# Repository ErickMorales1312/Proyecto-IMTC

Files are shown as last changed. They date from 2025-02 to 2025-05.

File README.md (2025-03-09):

# Proyecto-IMTC
**IoT Project for Autonomous Firefighting and Fire Detection System**

## Structure
This repo consists of the following folders:
1. **Scripts**: This folder is used for programming ESP32 (robot, cloud, detection modules).
2. **KiCad**: Electronic design projects for robot and detection modules, footprints, datasheet, BOM, etc.
3. **Docs**: Word, ppt, excel documents.
4. **Workflow**: Algorithms designed (diagrams, etc).
5. **Test**: Save simple codes for testing components.

**Commits**: 
For better organization, set commits as:
- chore: Updates of tasks
- Test: Testing components, repetitive code useful
- feat: Adding new feature on the project
   
## Step by Step Guide

### Setup
1. **Install Git Bash**
   - Download and install Git Bash from: https://gitforwindows.org/

### Configure Git
   - Set your username and email in Git Bash or command prompt.
       ```bash
        git config --global user.name "Your Name"
        git config --global user.email "your.email@example.com"

**Note** You can refer to this YouTube tutorial for guidance. (https://www.youtube.com/watch?v=8JJ101D3knE)

### Clone Repository
1. **Get the Repository Link**
   - Go to Proyecto-IMTC GitHub Repository.
   - Click on the green "Code" button and copy the HTTP link.

2. **Clone the Repository**
   - Open File Explorer and navigate to the folder where you want to save the repository.
   - Open Git Bash in the selected directory and run the following command:
     ```bash
     git clone <HTTP_LINK>

### Using Command Prompt 
You can use git -h to see more details about each Git instruction. 

## Commits and Create New Branches
### 1. Create a New Branch
   - Open the command prompt, locate the repository folder and run the following command:
     ```bash
     git branch <Name of the new branch>

### 2. **Checkout**
   - Change the main branch to new branch using the following command:
     ```bash
     git checkout <Name of the new branch>
   Then, you can save your work on this branch and commit changes.

### 3. **Commit changes**
   - Add modified files using:
     ```bash
        git add <name of the file> #for a specific file
        git add . #for all updated files
   - Make a commit 
     ```bash
        git commit -m <"name of commit">

### 4. **Push Branch to Remote**
   - At this point, your local changes are stashed temporarily, but to save your changes on the branch, you should push the branch to remote repository, using:
      ```bash
      git push origin <Name of the new branch>

### 5. **Create a PR**
   - Make a PR to merge your changes into main branch.

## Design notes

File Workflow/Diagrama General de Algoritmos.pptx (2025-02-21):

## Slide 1

IoT Autonomous Fire Detection and Firefighting System

Servicio en la nube

1. Escuchar continuamente por nueva informaciónón proveniente de los módulos de detección
2. En el momento en el que reciba nueva información, enviarla al vehículo

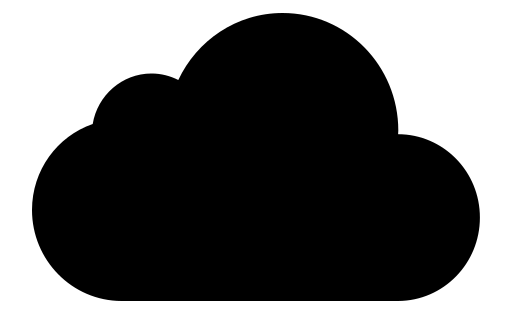
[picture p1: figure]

Vehículo autónomo de respuesta

Módulos de detección

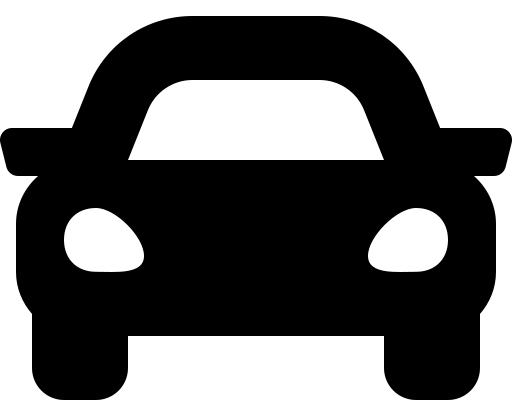
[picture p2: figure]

1. Escuchar continuamente por señales de alerta
2. En el momento en el que reciba una señal de alerta, dirigirse a la localización GPS recibida
3. Mitigar el incendio

1. Leer continuamente los datos de los sensores
2. Procesar los datos para definir si existe un incendio
3. En el momento en el que detecte un incendio, enviar la señal de la alerta a la nube, junto con las lecturas de los sensores y la información del GPS

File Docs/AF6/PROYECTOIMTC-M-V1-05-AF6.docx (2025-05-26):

UNIVERSIDAD AUTÓNOMA DE NUEVO LEÓN

FACULTAD DE INGENIERÍA

MECÁNICA Y ELÉCTRICA

PROYECTO DE IMTC

ACTIVIDAD FUNDAMENTAL 6:

DISEÑO MECÁNICO Y/O ELECTRÓNICO

EQUIPO 05

MATRÍCULA | NOMBRE | PE
1966252 | CONSTANTE MALDONADO KEVIN YAIR | IMC
1964189 | MORALES ESCOBEDO ERICK RUBEN | IMC
2078113 | SANCHEZ MELENDEZ OSWALDO | IMC

TÍTULO DEL PROYECTO:

“IoT Autonomous Fire Detection and Firefighting System”

ASESOR: DR. ERICK DE JESÚS ORDAZ RIVAS

GRUPO: 008 HORA: MARTES V1

SEMESTRE: ENERO - JUNIO 2025

FECHA DE ENTREGA: 04 DE MARZO DEL 2025

CIUDAD UNIVERSITARIA A 04 DE MARZO DEL 2025

# Introducción

El desarrollo del presente proyecto implicó el diseño integral de un sistema enfocado en la detección y mitigación de incendios, mediante la implementación de un vehículo autónomo de respuesta, módulos de detección distribuidos y un sistema de almacenamiento y suministro de agua. Para lograr una solución funcional y eficiente, se llevó a cabo un diseño mecánico y electrónico cuidadosamente planificado, permitiendo la integración estructural y operativa de todos los componentes involucrados.

Desde el enfoque mecánico, se diseñaron tres elementos clave: el vehículo autónomo, los módulos de detección y el tanque de almacenamiento. El vehículo se conforma de dos estructuras principales: una base inferior, encargada de alojar los motores, el eje de las ruedas traseras y los sensores ultrasónicos, y una base superior con perforaciones destinadas a la fijación de elementos adicionales. Además, se incorporó un separador interno que divide el espacio interno en dos zonas: una para los actuadores y otra para la electrónica de control, con el objetivo de evitar interferencias y facilitar el mantenimiento. En los módulos de detección se siguió un enfoque similar, con una base inferior que permite una instalación firme de los sensores, así como pilares para el montaje del microcontrolador. Finalmente, el tanque de agua fue diseñado con aberturas estratégicas que permiten la conexión eficiente con la bomba y la manguera, asegurando el suministro del líquido ante una posible emergencia.

En cuanto al diseño electrónico, se desarrollaron dos circuitos impresos (PCB), cada uno adaptado a las necesidades del subsistema correspondiente. El circuito del vehículo autónomo integra un microcontrolador ESP32, un módulo GPS Neo-7M, un magnetómetro HMC5887, sensores ultrasónicos para navegación, un módulo L298N para el control de los motores y baterías recargables 18650 mAh como fuente de alimentación. Por otro lado, los módulos de detección están equipados con sensores de flama, gas, temperatura y humedad, todos gestionados mediante un microcontrolador ESP32 y alimentados por una batería de 3.7V. Esta disposición garantiza una operación autónoma, continua y segura en entornos dinámicos.

La relevancia de este diseño radica en su enfoque integral, el cual permite no solo detectar condiciones de riesgo en tiempo real, sino también actuar de forma autónoma en escenarios donde la intervención humana podría verse limitada. La adecuada integración entre los componentes mecánicos y electrónicos permite que el sistema funcione de manera coordinada, brindando una solución eficaz para la atención temprana de emergencias relacionadas con incendios en espacios remotos o de difícil acceso.

# Objetivo del Diseño

Diseñar un sistema de detección y mitigación de incendios compuesto por un vehículo autónomo de respuesta y módulos de detección cuyo propósito principal es detectar y mitigar incendios a pequeña escala de manera autónoma. El sistema medirá niveles de CO2, humedad, temperatura y presencia de flama, y enviará la información recopilada a través de un servicio en la nube para un monitoreo en tiempo real. Además, el vehículo autónomo será capaz de evadir obstáculos y utilizará GPS para que los incendios puedan ser localizados con precisión y sean atendidos con anticipación.

# Diseño Mecánico

A continuación, se muestran los planos técnicos de cada una de las piezas que conforman el sistema:

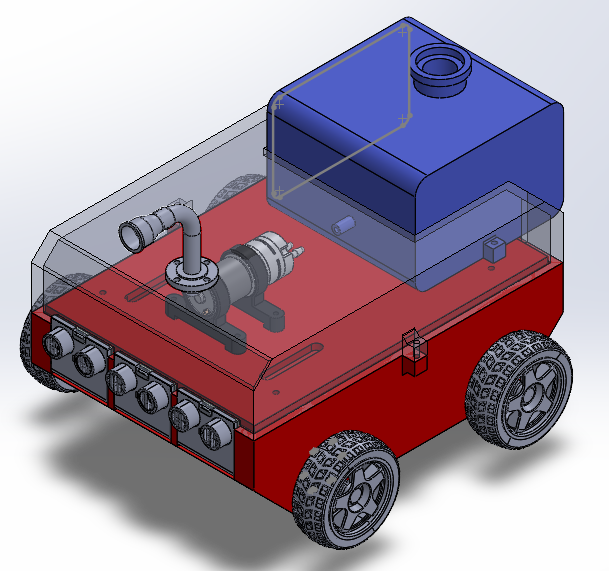
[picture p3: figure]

Figura 1. Ensamble general

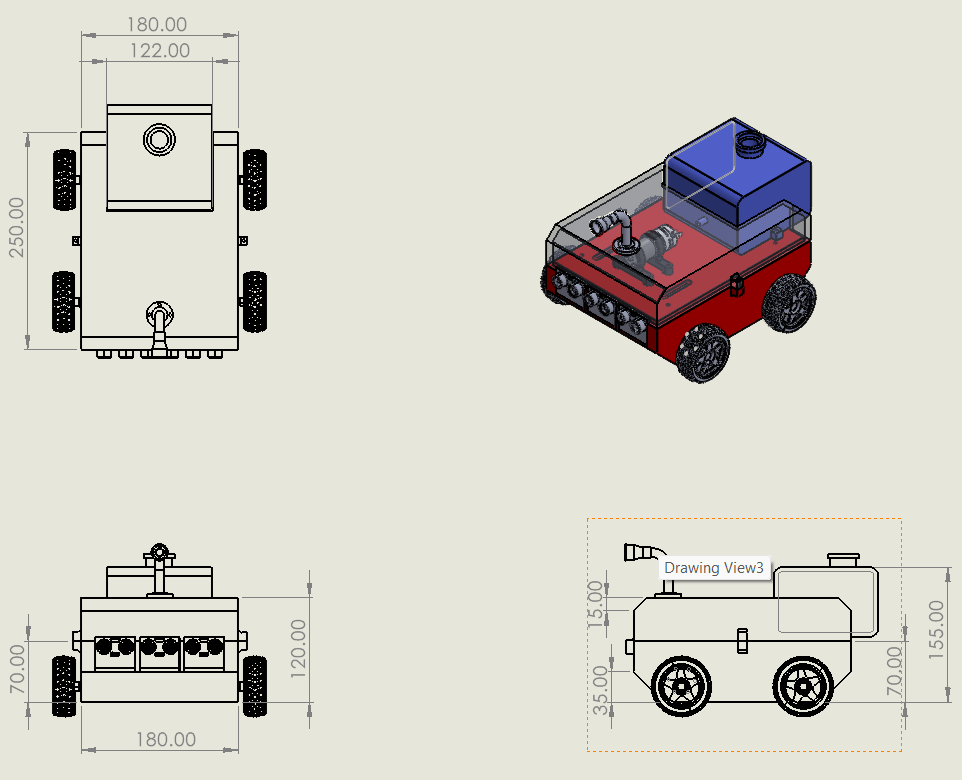
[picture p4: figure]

Figura 2. Plano técnico de ensamble general

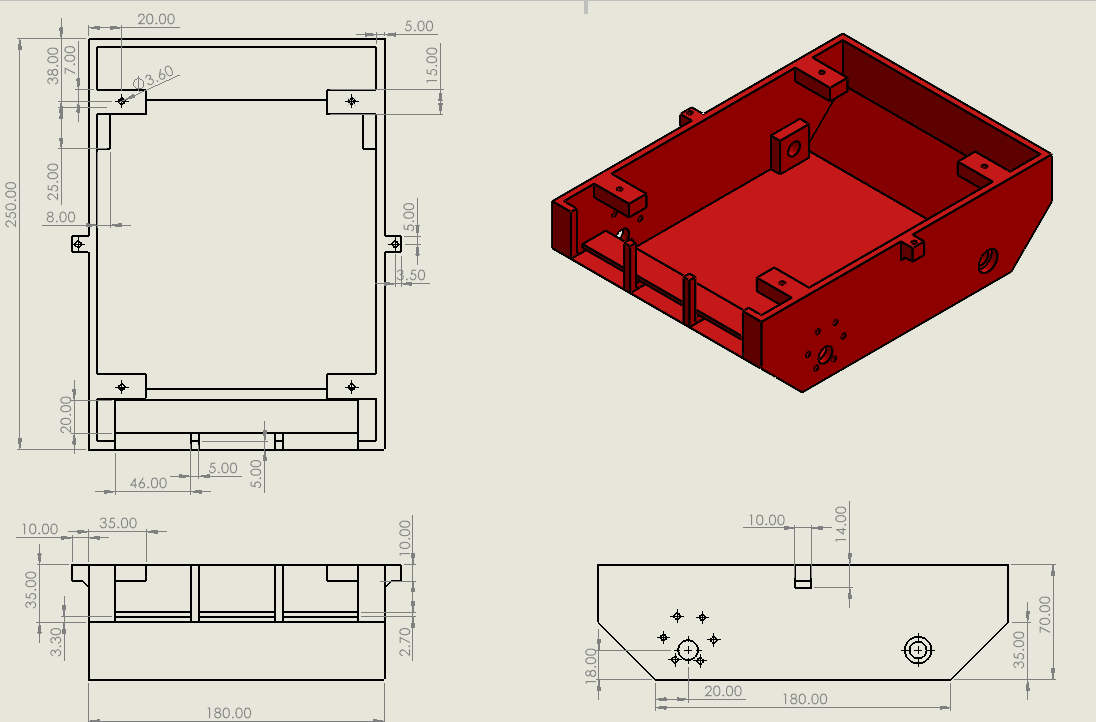
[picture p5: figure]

Figura 3. Base inferior

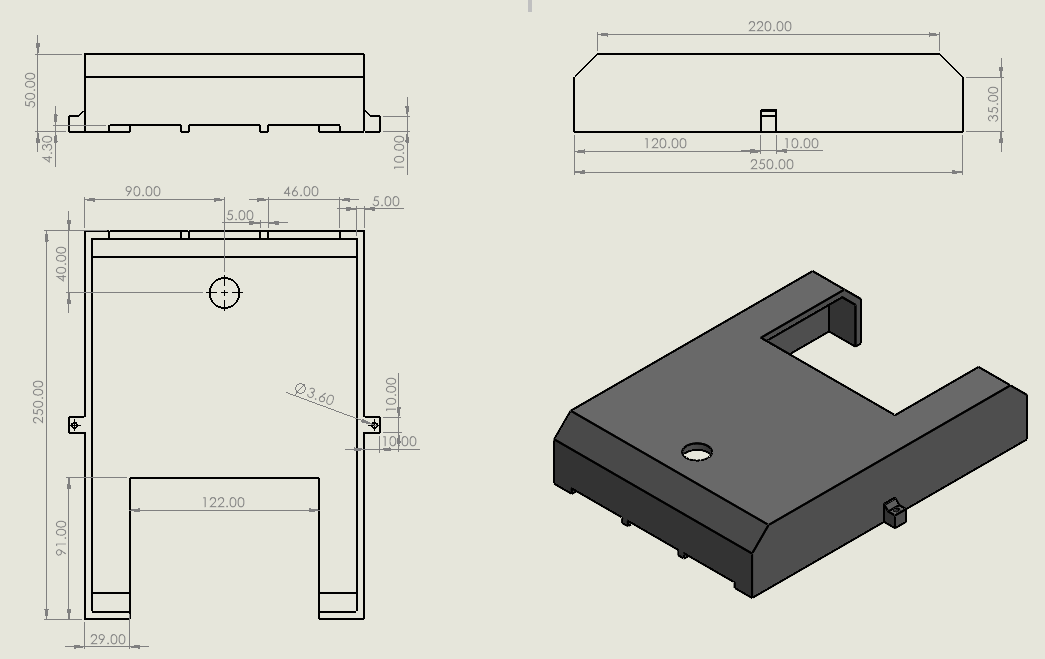
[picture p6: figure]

Figura 4. Base superior

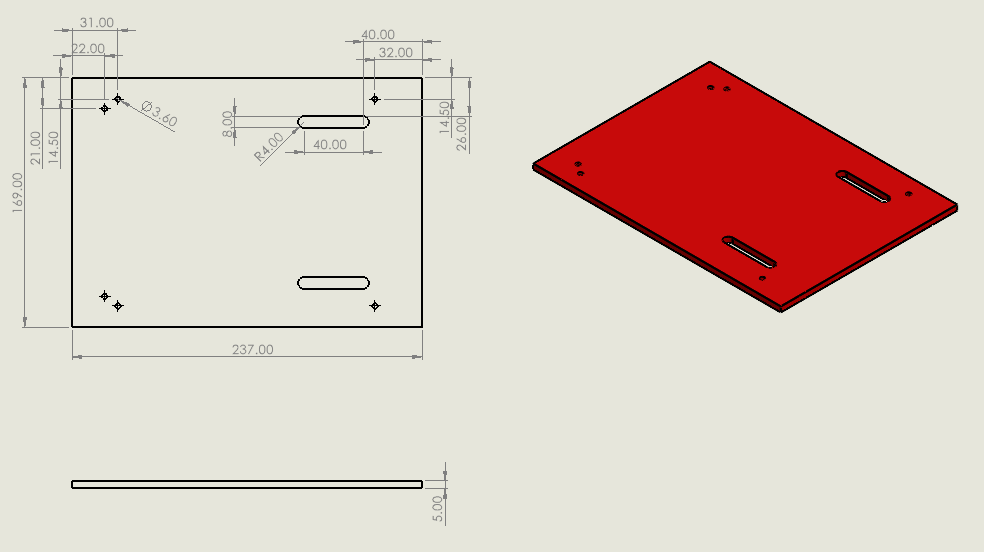
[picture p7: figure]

Figura 5. Separador

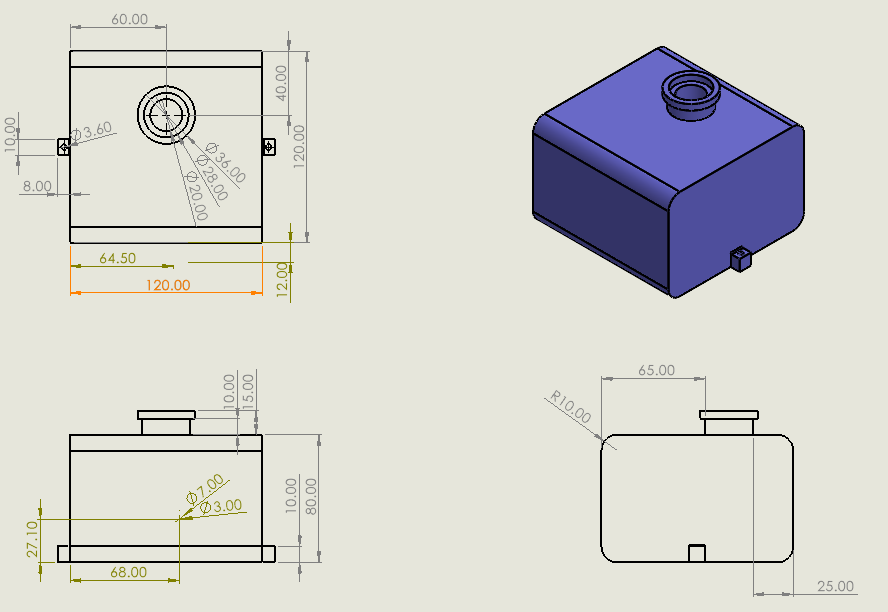
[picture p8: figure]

Figura 6. Tanque usado para la mitigación de incendios

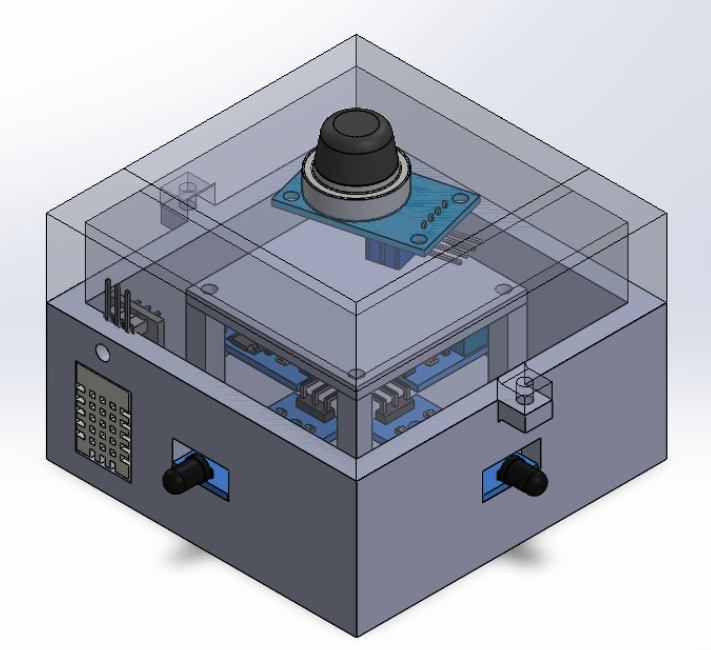
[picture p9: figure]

Figura 7. Bosquejo de los módulos de detección

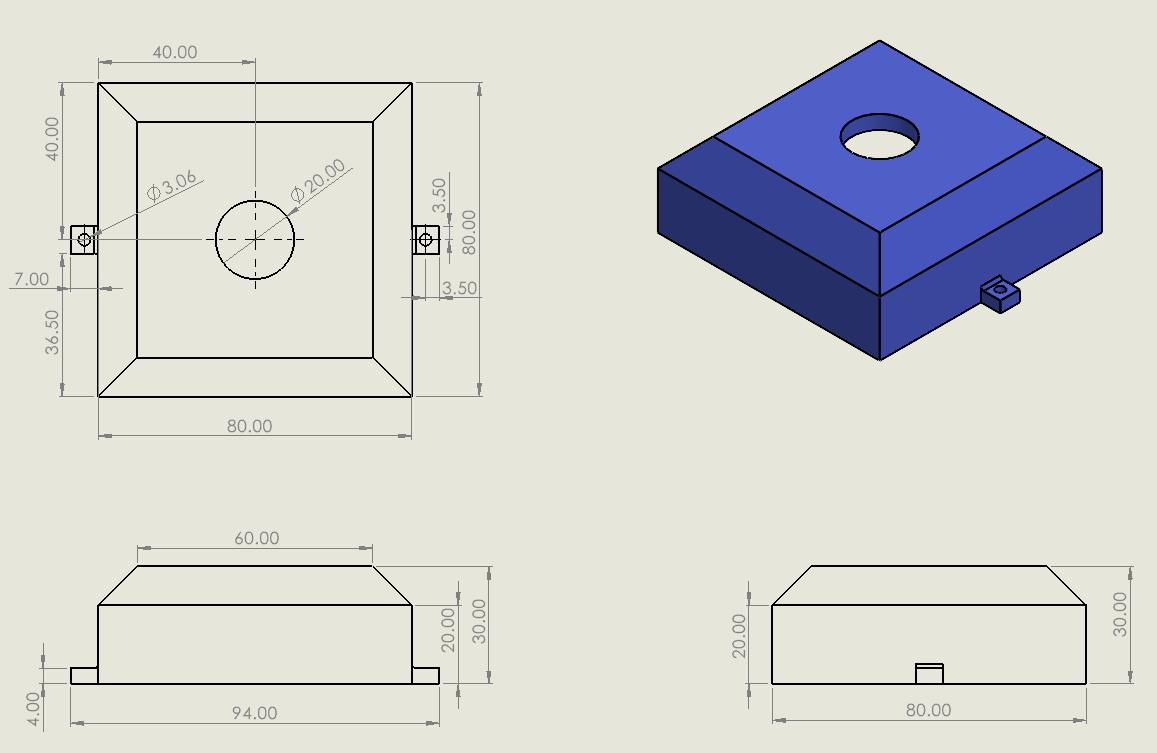
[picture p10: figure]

Figura 8. Plano general de la base superior

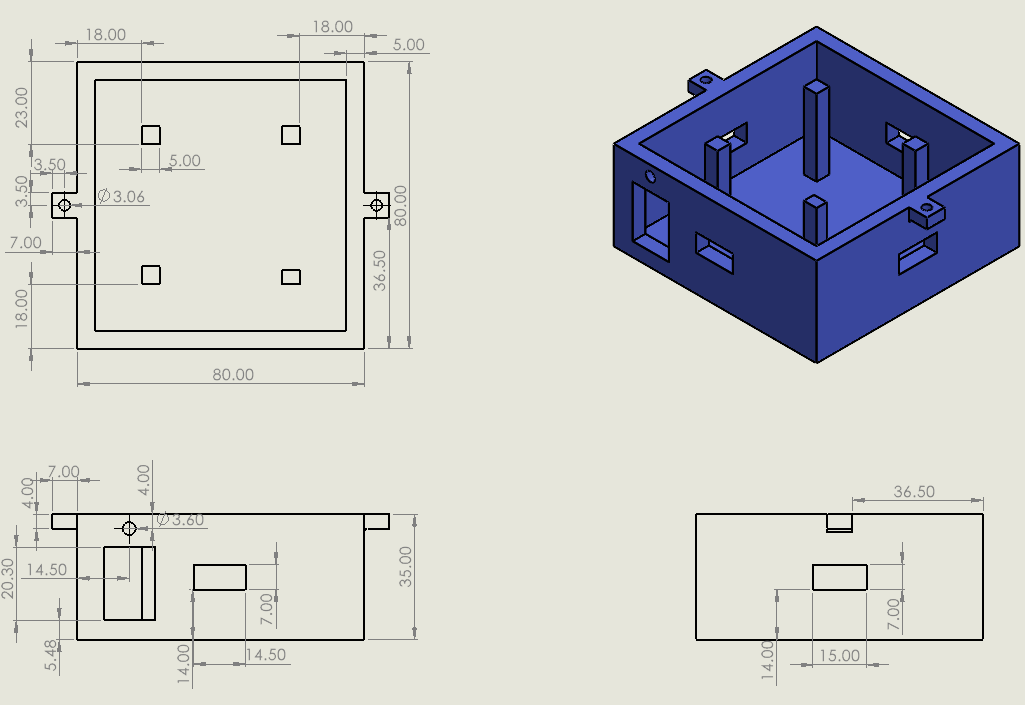
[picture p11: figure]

Figura 9. Plano general de la base superior

# Diseño Electrónico

El objetivo de este proyecto consiste en diseñar un sistema de detección y mitigación que integre sensores de temperatura, humo y llama, con comunicación inalámbrica para el envío de alertas y monitoreo remoto. El sistema incluirá un robot autónomo capaz de desplazarse y evadir obstáculos, equipado con una unidad de control para procesar datos provenientes de los sensores y un sistema de control para la activación y operación de una bomba de agua destinada a mitigar el incendio. Además, se implementará un sistema de alimentación eficiente para garantizar su funcionamiento prolongado.

Entre los desafíos se encuentran la gestión del consumo energético, la evasión de obstáculos, navegación autónoma y la precisión en la localización y mitigación de incendios. Para el desarrollo de este proyecto, se proponen los siguientes diagramas electrónicos:

## Diagramas de conexión

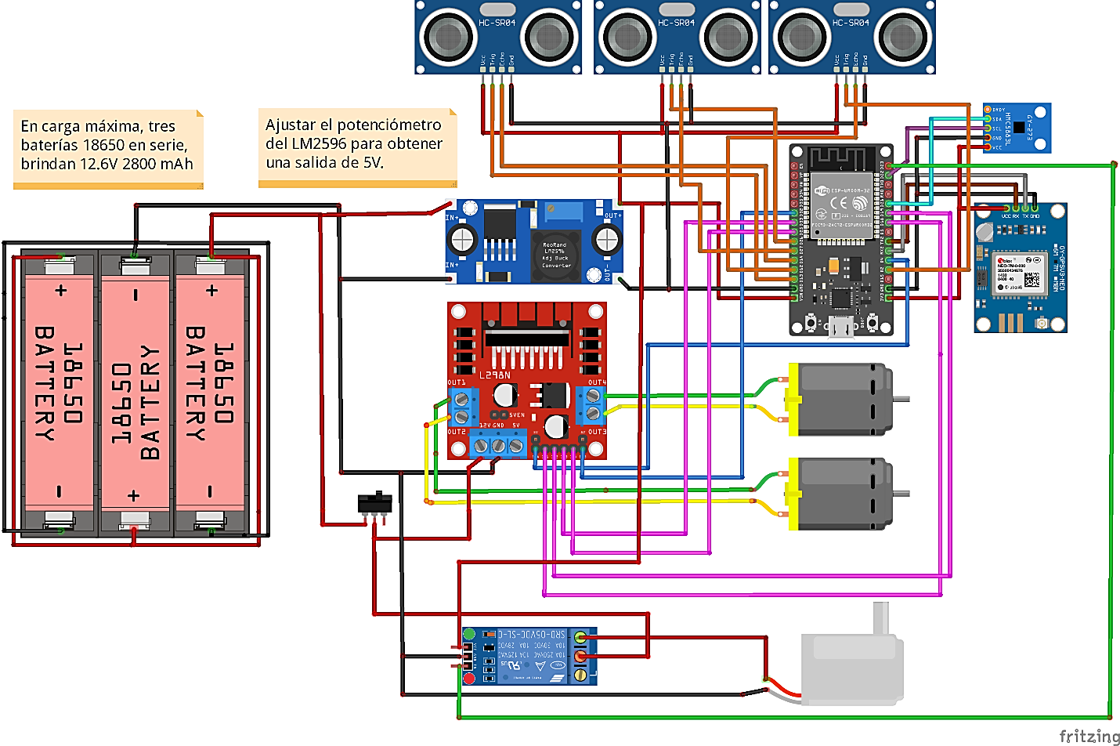
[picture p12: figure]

Figura 10. Diagrama de conexiones del sistema de navegación y mitigación de incendios

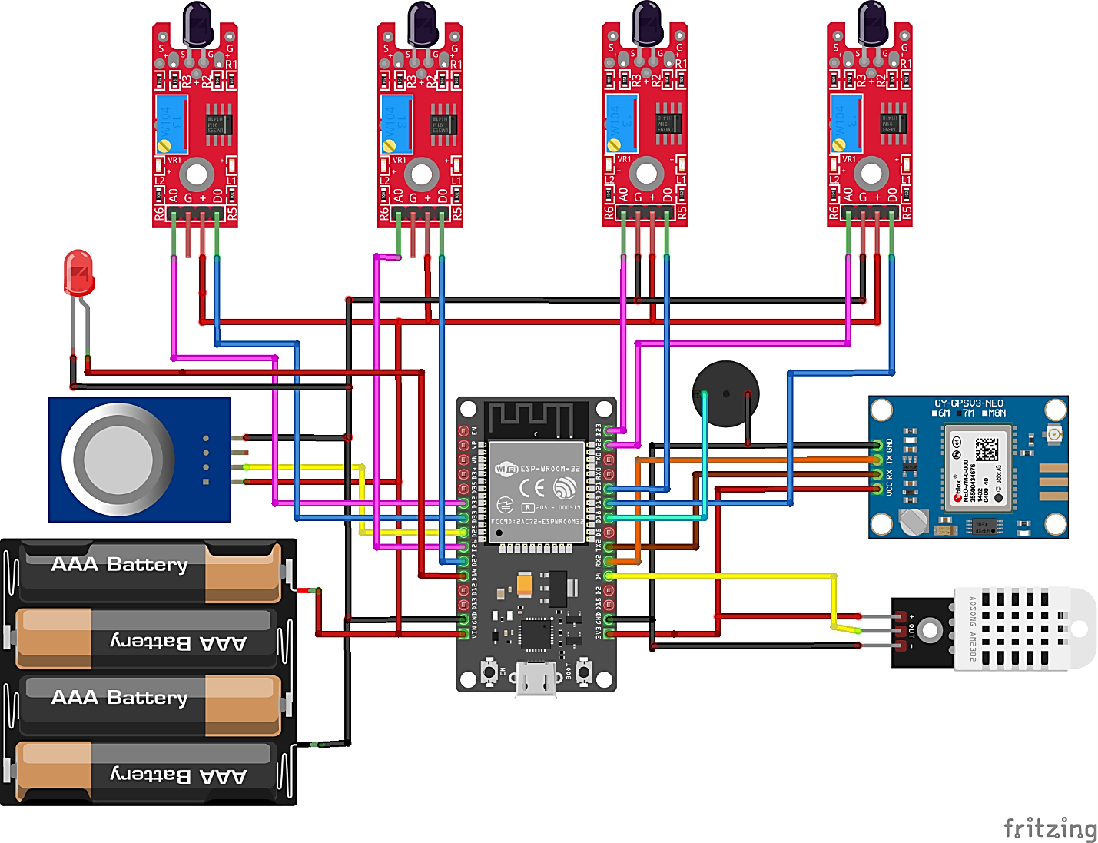
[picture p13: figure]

Figura 11. Diagrama de conexiones de los módulos de detección de incendios

## Diagramas esquemáticos

Para el desarrollo de este proyecto, se han diseñado diagramas esquemáticos utilizando KiCad, una herramienta de software libre para la creación de circuitos electrónicos. Estos diagramas son fundamentales para la integración de los sensores de temperatura, humo y llama, así como para la comunicación inalámbrica y el control del robot autónomo. A continuación, se presentan los diagramas esquemáticos que ilustran la arquitectura electrónica del sistema de detección y mitigación de incendios.

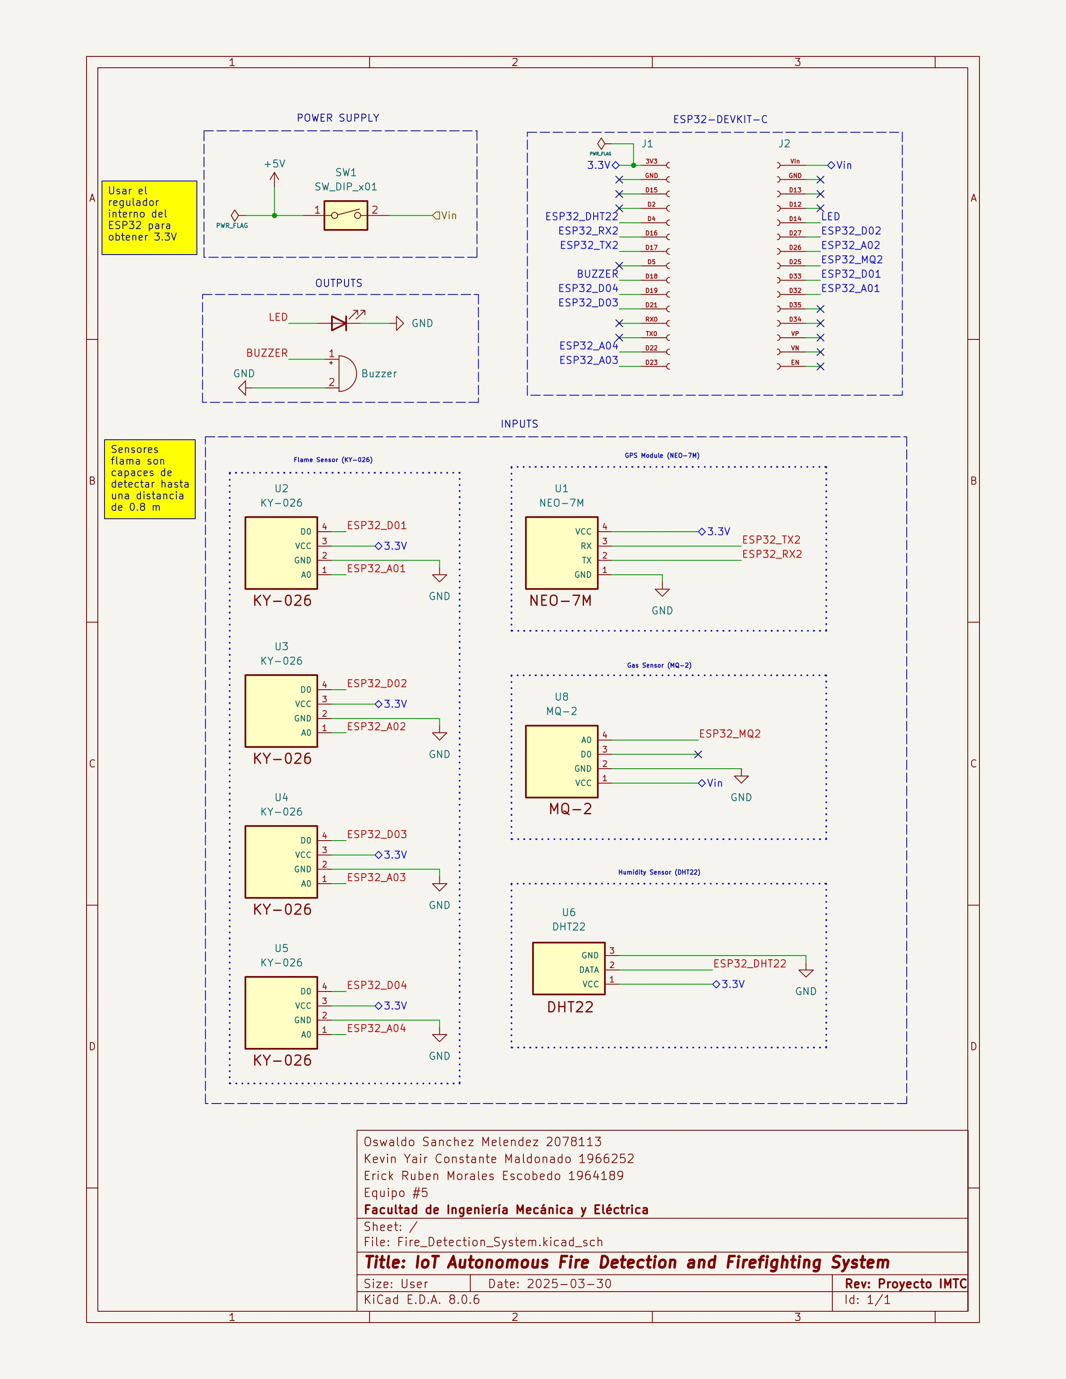
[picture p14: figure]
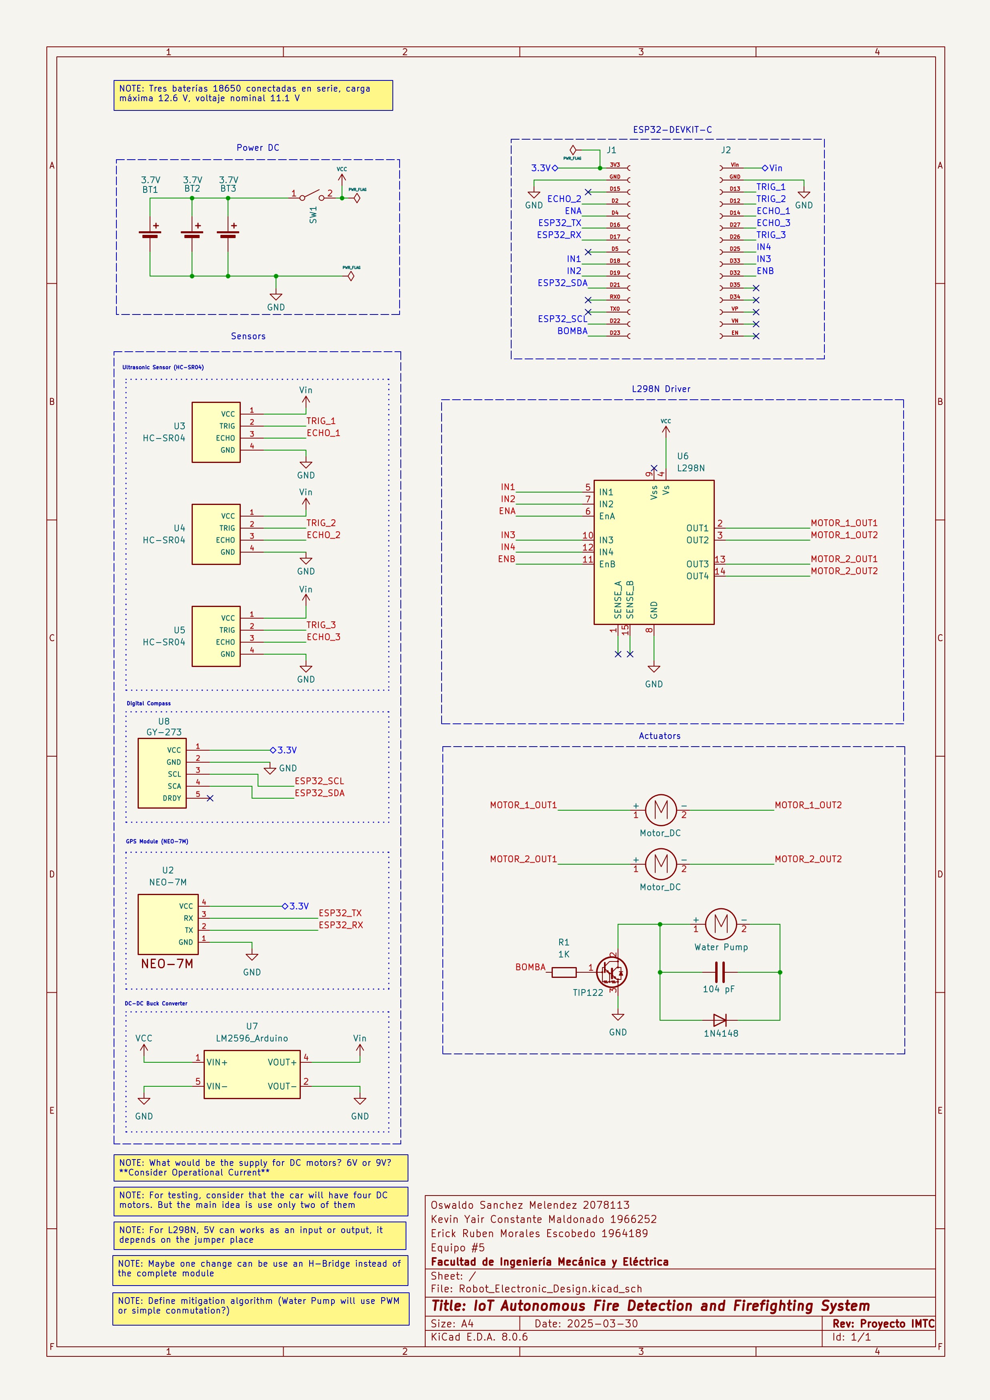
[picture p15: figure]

## Especificaciones técnicas

### ESP32 Devkit V1

El ESP32 es un microcontrolador desarrollado por Espressif Systems, que combina capacidades de procesamiento con conectividad inalámbrica. Este dispositivo es particularmente popular en proyectos de robótica, debido a su bajo costo, versatilidad y potencia. Este dispositivo integra tecnología Wi-Fi y Bluetooth, lo que lo hace ideal para aplicaciones de Internet de las Cosas (IoT) y proyectos de robótica.

Arquitectura

El ESP32 cuenta con un microprocesador de 32 bits, específicamente el modelo Tensilica Xtensa LX6, que puede configurarse en modo de núcleo único o de doble núcleo. Cada núcleo puede operar a una frecuencia de hasta 240 MHz, lo que permite realizar tareas complejas y múltiples procesos simultáneamente. Esta arquitectura proporciona un rendimiento superior en comparación con microcontroladores como el ESP8266 y el Arduino UNO.

En cuanto a la memoria, el ESP32 incluye varias formas:

- SRAM: 520 kB de SRAM, que se utiliza para almacenar variables y datos temporales durante la ejecución del programa.
- Flash: Capacidad de almacenamiento de hasta 16 MB (dependiendo del modelo), que se utiliza para el firmware y otros datos persistentes.
- EEPROM: 448 kB, que permite almacenar configuraciones y datos que deben persistir entre reinicios.

Conectividad

El ESP32 es conocido por su capacidad de conectividad dual:

- Wi-Fi: Soporta el estándar 802.11 b/g/n, permitiendo conexiones a redes locales y la creación de puntos de acceso. Esto facilita la comunicación con otros dispositivos y el acceso a internet.
- Bluetooth: Compatible con Bluetooth Classic y Bluetooth Low Energy, lo que permite la interacción con una amplia gama de dispositivos Bluetooth.

#### Interfaces Periféricas

El microcontrolador ofrece una variedad de interfaces que permiten la conexión a sensores, actuadores y otros dispositivos. A continuación, se muestra un esquema con la distribución de pines en el ESP32.

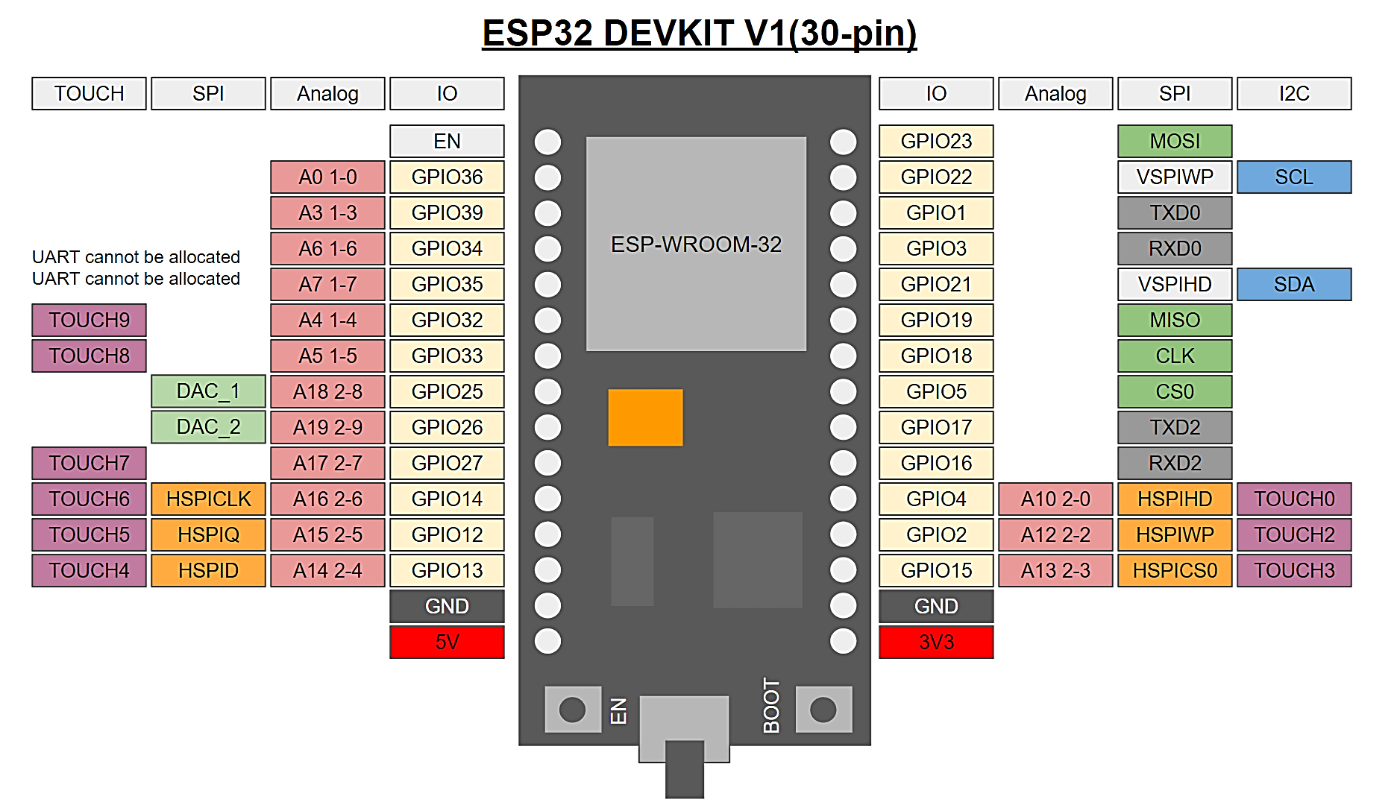
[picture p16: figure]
Pinout of various ESP32 modules and Raspberry Pi | そう備忘録

Figura 12. ESP32 DevKit V1 pinout

El ESP32 cuenta con múltiples versiones, cada una con diferentes configuraciones. Para este proyecto se tomó en cuenta el modelo DevKit V1, el cual cuenta con las siguientes características:

- GPIO (Pines de Entrada / Salida): Hasta 34 pines GPIO que pueden ser configurados como entradas o salidas digitales. Muchos de estos pines también suelen ser utilizados para funciones específicas como PWM, ADC, etc.
- ADC (Convertidor Analógico – Digital): Incluye un ADC de 12 bits con hasta 18 canales, lo que permite la lectura de múltiples sensores analógicos.
- PWM (Modulación por Ancho de Pulsos): Soporta hasta 16 canales PWM, lo que es útil para controlar la intensidad de actuadores como LEDs, motores, etc.
- UART: Dispone de tres interfaces UART (0, 1 y 2) para comunicación serie asíncrona, soportando velocidades de hasta 5 Mbps.
- I2C y SPI: Con respecto a I2C, cuenta con dos interfaces que permiten conectar hasta 112 dispositivos en un solo bus. Los pines por defecto son GPIO21 (SDA) y GPIO22 (SCL), pero se pueden reconfigurar. Por otra parte, cuenta con 3 buses SPI capaces de alcanzar hasta 80 MHz.

#### Consumo energético

El ESP32 puede alimentarse a través del puerto micro-USB (5V) o directamente por el pin VIN. Internamente, regula el voltaje a 3.3V, que es el nivel lógico de operación. El consumo de corriente varía según del uso, pero típicamente consume 160 mA en transmisión activa, con picos mayores. A continuación, se muestran los valores de alimentación recomendados y absolutos para el ESP32 DevKit V1, basada en la documentación oficial de Espressif.

Figura 13. Valores máximos absolutos

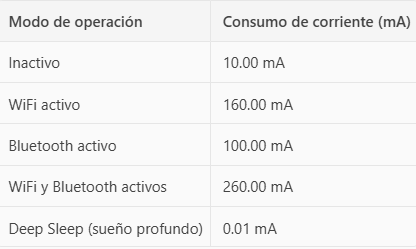
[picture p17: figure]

Figura 14. Consumo ESP32 con diferentes modos de operación

### Brújula digital GY-273

El GY-273 es un módulo de brújula digital basado en el sensor HMC5883L de Honeywell. Este dispositivo permite medir el campo magnético terrestre en tres ejes (X, Y, Z), lo que lo convierte en una herramienta ideal para determinar orientación y dirección en proyectos de navegación, robótica móvil y sistemas de geolocalización.

Arquitectura

El núcleo del GY-273 es el HMC5883L, un magnetómetro digital de 3 ejes que utiliza tecnología de magnetorresistencia anisotrópica (AMR) para detectar campos magnéticos. Este sensor convierte las señales analógicas de los tres ejes en datos digitales mediante un convertidor ADC interno de 12 bits.

- El módulo GY-273 incluye:
- El chip HMC5883L
- Filtros pasivos (condensadores) para estabilizar la señal
- Pines de conexión estándar (SCL, SDA, VCC, GND)
- En algunos modelos, un regulador de voltaje para aceptar entradas de 5V (aunque el sensor opera a 3.3V internamente)

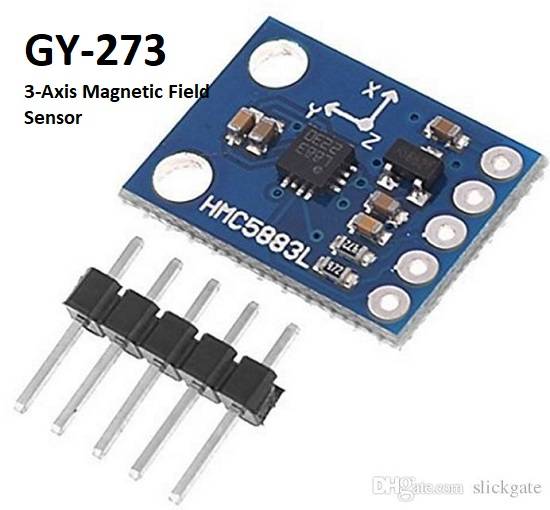
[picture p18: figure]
GY-273 3-Axis Magnetic Field Sensor Magnetometer GY273 HMC5883 - GY-273
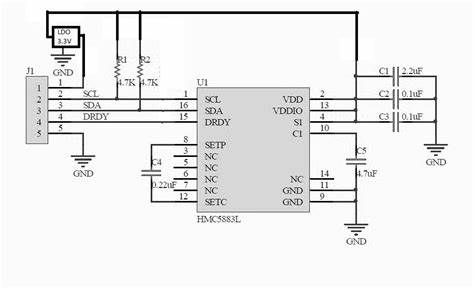
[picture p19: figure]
HMC5883L Triple-Axis Magnetometer Compass Module GY-273

Figura 15. GY-273

#### Conectividad

El GY-273 se comunica mediante el protocolo I2C, lo que permite una integración sencilla con microcontroladores. Los pines típicos son:

- VCC: Alimentación (3.3V – 5V dependiendo del modelo)
- GND: Tierra
- SCL: Reloj I2C
- SDA: Datos I2C

#### Consumo energético

A continuación, se muestran los valores de alimentación recomendados y absolutos para el HMC5883L, basada en la documentación oficial de Honeywell.

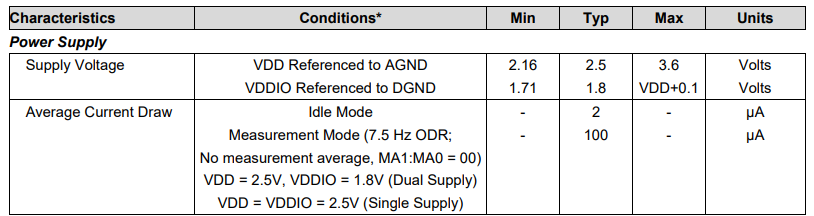
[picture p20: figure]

Figura 16. Características eléctricas del GY-273

No obstante, el módulo proporciona otras características importantes para el funcionamiento dentro del sistema de navegación autónoma.

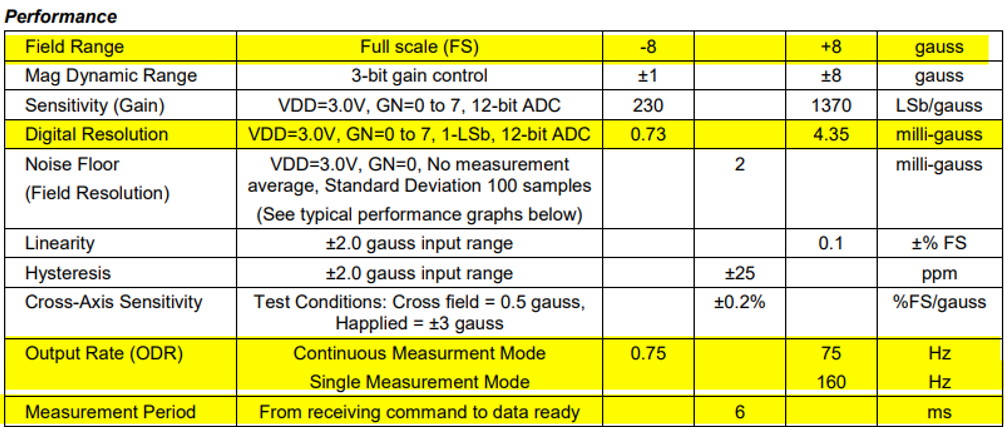
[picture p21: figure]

Figura 17. Propiedades de funcionamiento

### Módulo GPS (NEO-7M)

El NEO-7M es un módulo GPS desarrollado por u-blox, diseñado para proporcionar datos de posicionamiento global con alta precisión y bajo consumo energético. Es ampliamente utilizado en aplicaciones de geolocalización, navegación autónoma, drones, vehículos robóticos y sistemas de rastreo.

Arquitectura

El núcleo del módulo es el chip u-blox NEO-7M, que integra un receptor GNSS (Global Navigation Satellite System) capaz de recibir señales del sistema GPS (y opcionalmente QZSS). El módulo incluye:

- Receptor GPS de 50 canales
- Antena cerámica integrada (en algunos modelos)
- EEPROM para almacenamiento de configuración
- Batería de respaldo (RTC) para mantener datos de tiempo y posición

El NEO-7M puede lograr una precisión de posicionamiento de hasta 2.5 metros en condiciones óptimas.

#### Conectividad

El módulo se comunica principalmente mediante UART (TTL), aunque también puede configurarse para usar I2C o SPI en versiones avanzadas. Los pines típicos son:

Figura 18. NEO-7M

- VCC: 3.3V – 5V
- GND: Tierra
- TX: Transmisión de datos (hacia el microcontrolador)
- RX: Recepción de comandos (desde el microcontrolador)
- PPS: Señal de pulso por segundo (útil para sincronización precisa)

#### Interfaces periféricas

El NEO-7M utiliza el protocolo NMEA 0183 para transmitir datos de navegación. Este protocolo es un estándar ampliamente adoptado en sistemas GPS y marinos, y consiste en cadenas de texto ASCII que contienen información estructurada sobre posición, velocidad, tiempo, y más.

Cada línea de datos NMEA se denomina sentencia, y comienza con un signo de dólar ($), seguido de un identificador de tipo de mensaje y una serie de campos separados por comas. Algunos ejemplos comunes incluyen:

- $GPGGA: Información de posición global (latitud, longitud, altitud, número de satélites, precisión)
- $GPRMC: Datos mínimos recomendados: hora, fecha, velocidad, rumbo
- $GPGSV: Información sobre los satélites visibles
- $GPGSA: Información sobre la precisión y los satélites usados

#### Consumo energético

A continuación, se muestran los valores de alimentación recomendados y absolutos para el NEO-7M, basada en la documentación oficial de Ublox.

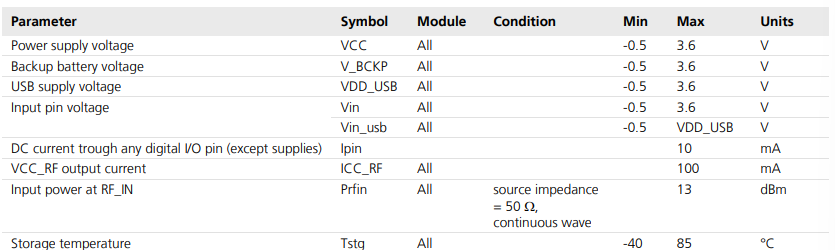
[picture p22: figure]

Figura 19. Propiedades electricas del NEO-7M

### L298N

El L298N es un módulo controlador de motores basado en el circuito integrado L298, fabricado por STMicroelectronics. Este módulo es ampliamente utilizado en robótica y automatización para controlar motores de corriente directa (DC) y motores paso a paso, permitiendo cambiar la dirección de giro y controlar la velocidad mediante señales PWM.

#### Arquitectura

El núcleo del módulo es el L298N, un puente H dual que permite controlar dos motores DC de forma independiente o un motor paso a paso bipolar. El módulo incluye:

- Dos canales de salida (OUT1/OUT2 y OUT3/OUT4)
- Pines de control de dirección (IN1–IN4)
- Pines de habilitación (ENA y ENB) para activar cada canal
- Regulador de voltaje de 5V (puede alimentar microcontroladores si se habilita)
- Terminales de tornillo para conexiones de potencia y motores

El diseño del puente H permite invertir la polaridad de la tensión aplicada al motor, lo que permite cambiar su dirección de rotación.

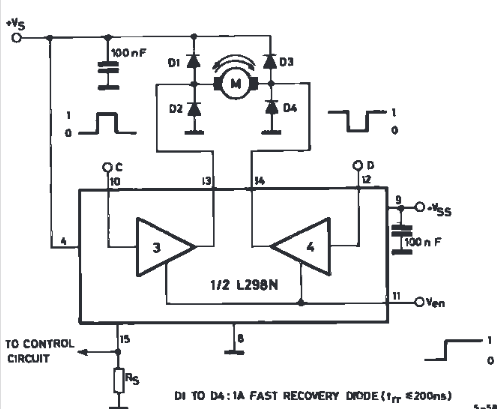
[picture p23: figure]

Figura 20. L298N

#### Conectividad

El módulo se conecta fácilmente a un microcontrolador como el ESP32 mediante pines digitales:

- IN1, IN2: Controlan el motor A
- IN3, IN4: Controlan el motor B
- ENA, ENB: Activan o desactivan cada motor (pueden conectarse a PWM para control de velocidad)
- VCC: Alimentación del motor (hasta 12V)
- GND: Tierra común
- 5V: Salida de 5V si se habilita el regulador interno (jumper)

Cabe mencionar que, si se alimenta con más de 12V, se recomienda configurar el jumper de 5V para evitar dañar el regulador.

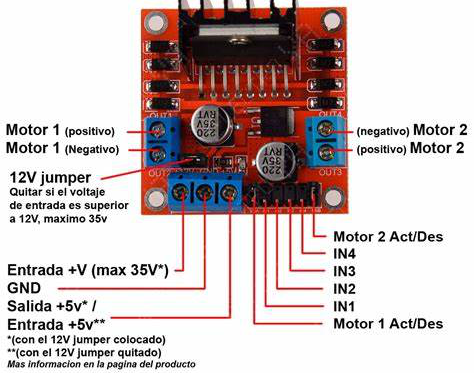
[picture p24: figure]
L298n motor driver how to connect to arduino - dsaepunch

Figura 21. L298N pinout

#### Consumo energético

A continuación, se muestran los valores de alimentación recomendados y absolutos para el L298N, basada en la documentación oficial de STMicroelectronics.


### Sensor de flama (KY-026)

El KY-026 es un sensor diseñado para detectar la presencia de una fuente de calor o flama, especialmente aquellas que emiten luz infrarroja en el rango de 760 nm a 1100 nm. Es comúnmente utilizado en sistemas de alarma contra incendios, robots bomberos y proyectos de seguridad.

El funcionamiento de este sensor radica en el uso de un fotodiodo infrarrojo sensible a la radiación emitida por las llamas. Cuando detecta una fuente de calor intensa (como una vela o encendedor), genera una señal de salida que puede ser leída por un microcontrolador.

#### Conectividad

- VCC: Alimentación
- GND: Tierra
- D0: Salida digital (activada cuando se detecta flama)
- A0: Salida analógica (valor proporcional a la intensidad)

#### Consumo energético

- Voltaje de operación: 3.3V – 5V
- Corriente típica: ~20 mA
- Distancia de detección: Hasta 80 cm (dependiendo de la intensidad de la flama)
- Ángulo de detección: ~60°
- Salida digital (D0): Alta o baja según detección
- Salida analógica (A0): Nivel proporcional a la intensidad de la luz infrarrojo

### Sensor de gas MQ-2

El MQ-2 es un sensor de gas ampliamente utilizado para detectar gases inflamables y humo en el aire. Es ideal para sistemas de alarma contra incendios, monitoreo de calidad del aire y proyectos de seguridad doméstica o industrial. El sensor MQ-2 utiliza un elemento sensible de óxido de estaño (SnO₂), cuya conductividad cambia en presencia de gases combustibles. A mayor concentración de gas, menor es la resistencia del sensor, lo que permite medir la presencia de gases como propano, metano, humo, alcohol e hidrógeno.

#### Conectividad

- VCC: 5V
- GND: Tierra
- D0: Salida digital (activada si se supera el umbral)
- A0: Salida analógica (valor continuo proporcional)

#### Consumo energético

- Voltaje de operación: 5V
- Corriente típica: ~150 mA
- Tiempo de precalentamiento: 20 segundos (óptimo: 24–48 h para calibración)

### Sensor de temperatura DHT22

El DHT22, también conocido como AM2302, es un sensor digital que mide la temperatura y la humedad relativa del ambiente. Es ampliamente utilizado en estaciones meteorológicas, sistemas de control climático y proyectos de automatización del hogar. El DHT22 contiene un sensor capacitivo de humedad y un termistor para medir la temperatura. Internamente, convierte las señales analógicas en datos digitales y los transmite a través de un solo pin de datos.

#### Conectividad

- VCC: Alimentación
- GND: Tierra
- DATA: Pin digital de datos (requiere resistencia pull-up de 4.7kΩ)
- Comunicación: protocolo propietario de un solo hilo (one-wire, no compatible con el protocolo Dallas)

#### Consumo energético

- Voltaje de operación: 3.3V – 6V
- Corriente en reposo: ~1.5 mA
- Corriente durante la medición: ~2.5 mA
- Rango de temperatura: -40 °C a +80 °C (±0.5 °C)
- Rango de humedad: 0% – 100% RH (±2% – 5%)
- Frecuencia de muestreo: 0.5 Hz (una lectura cada 2 segundos)

### Sensor ultrasónico

El HC-SR04 es un sensor de distancia que utiliza ondas ultrasónicas para medir la proximidad de objetos. Es muy utilizado en robótica para evitar obstáculos, medir niveles de líquido o realizar mapeo de entornos. El funcionamiento consiste en que el sensor emite un pulso ultrasónico (40 kHz) desde el emisor (Trigger) y mide el tiempo que tarda en rebotar y regresar al receptor (Echo). Usando la fórmula de distancia = velocidad × tiempo, calcula la distancia al objeto.

HC-SR04 Ultrasonic Module

#### Conectividad

- VCC: 5V
- GND: Tierra
- Trigger: Entrada digital (pulso de 10 µs)
- Echo: Salida digital (duración proporcional a la distancia)

#### Consumo energético

A continuación, se muestran los valores de alimentación recomendados y absolutos para el L298N, basada en la documentación oficial de STMicroelectronics.

### Motores DC

Los motores de corriente directa (DC) con una velocidad de salida de 350 revoluciones por minuto (RPM) son ampliamente utilizados en robótica móvil, automatización y sistemas de tracción. Estos motores suelen estar acoplados a una caja reductora que disminuye la velocidad de giro y aumenta el torque, lo que los hace ideales para mover estructuras con carga.

#### Consumo energético

- Voltaje de operación: 6V – 12V (algunos modelos hasta 24V)
- Corriente sin carga: ~100 – 300 mA
- Corriente con carga: ~500 mA – 1.5 A
- Velocidad nominal: 350 RPM
- Torque: ~2 – 5 kg·cm (dependiendo del modelo)
- Diámetro del eje: 6 mm (común)

### Bomba de diafragma

La bomba de diafragma es un tipo de bomba de desplazamiento positivo que utiliza un diafragma flexible para mover líquidos. Es ideal para aplicaciones donde se requiere un flujo controlado de agua u otros líquidos, como en sistemas de riego, robots de limpieza o dispensadores automáticos.

#### Consumo energético

- Voltaje de operación: 6V – 12V
- Corriente típica: 1 – 2 A
- Caudal: ~1 – 3 L/min (dependiendo del modelo)
- Presión máxima: ~80 – 120 psi
- Altura de succión: ~2 m
- Altura de descarga: ~5 – 7 m

# Análisis de Validación

## Cálculo del consumo energético del módulo de detección

Asumiendo que todos los componentes estarán activos simultáneamente durante una hora, el ESP32 se considera en WiFi activo, el MQ-2 y los sensores KY-026 tienen un consumo relativamente alto debido a su calentamiento interno y sensibilidad, el LED y el buzzer están encendidos de forma continua, se obtienen los siguientes resultados:

Componente | Consumo estimado
ESP32 DevKit V1 | 160 mA
4 x KY-026 (Sensor de Flama) | 80 mA
MQ-2 (Sensor de Gas) | 150 mA
LED | 20 mA
Buzzer | 30 mA
NEO-7M (GPS) | 45 mA
DHT22 (Temp/Humedad) | 2.5 mA
Total: | 487.5 mA

Cabe mencionar que los módulos deberán ser capaces de contar con voltajes de entrada de 3.3V y 5V. Por tanto, el consumo energético por hora está estimado en 487.5 mAh, sin embargo, el objetivo principal de estos módulos es realizar mediciones constantes durante largos periodos de tiempo, por lo que, si se incluye una batería 18650 2200 mAh, podría rendir alrededor de 4.51 horas, como se muestra en la siguiente fórmula:

Duración=(2200 mAh)/(487.5 mAh)=4.51 horas

No obstante, esos resultados están considerados con una eficiencia del 100%, en la práctica, las pérdidas por conversión de voltaje, temperatura y envejecimiento de la batería reducen la eficiencia, por lo tanto, si se considera un porcentaje de 85%, la duración está estimada en 3.84 horas, siendo unos resultados más realistas.

Cálculo del consumo energético del vehículo autónomo

Pruebas preliminares

  - Agregar la ss de Oswaldo con azure
  - Agregar prueba modulo gps
  - Agregar prueba de la brújula
  - Simular Proteus

Consumo energetico de los circuitos electronicos.

Enseguida se muestran las simulaciones que pertimen obtener el consumo energetico de cada uno de los circuitos electrónicos que conlleva el sistema:

## Consumo energético del módulo de detección.

_Poner Imagen_

## Consumo energético del vehículo autónomo

_Poner Imagen_

# Conclusión

Morales Escobedo Erick Rubén

TEXTO.

Sánchez Meléndez Oswaldo

TEXTO.

Constante Maldonado Kevin Yair

TEXTO.

# Referencias

- Adafruit Industries. (n.d.). AM2302 (wired DHT22) Temperature-Humidity Sensor
- ElecFreaks. (n.d.). HC-SR04 Ultrasonic Ranging Module Datasheet [PDF]. https://www.elecfreaks.com/download/HC-SR04.pdf
- Espressif Systems. (2023). ESP32 Series Datasheet [PDF]. https://www.espressif.com/sites/default/files/documentation/esp32_datasheet_en.pdf
- Seeed Studio. (n.d.). Grove - Gas Sensor (MQ2) [Web page]. https://wiki.seeedstudio.com/Grove-Gas_Sensor-MQ2/
- SparkFun Electronics. (n.d.). HMC5883L Triple Axis Magnetometer Breakout [Web page]. https://community.sparkfun.com/t/hmc5883l-how-to-establish-goog-heading-data/26151
- STMicroelectronics. (2023). L298 - Dual Full-Bridge Driver Datasheet [PDF]. https://www.st.com/resource/en/datasheet/l298.pdf
- Texas Instruments. (2023). LM2596 SIMPLE SWITCHER® Power Converter Datasheet [PDF]. https://www.ti.com/lit/ds/symlink/lm2596.pdf
- u-blox. (n.d.). NEO-7M GPS Module Datasheet [PDF]. https://www.u-blox.com/en/product/neo-7-series

# Anexos

## Repartición de tareas del equipo

Oswaldo Sánchez Meléndez: XXX

Erick Rubén Morales Escobedo: Redacción de la introducción y objetivo del diseño, simulaciones de consumo energético del vehículo de respuesta y módulos de detección y pruebas funcionales de los subsistemas que componen el diseño electrónico del sistema.

Kevin Yair Constante Maldonado: XXX

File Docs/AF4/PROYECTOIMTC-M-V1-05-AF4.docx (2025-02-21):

FIME UANL (@FIME_Oficial) | Twitter
La UANL será sede de la Universiada Nacional 2015 | Comisión ...

UNIVERSIDAD AUTÓNOMA DE NUEVO LEÓN

FACULTAD DE INGENIERÍA

MECÁNICA Y ELÉCTRICA

PROYECTO DE IMTC

ACTIVIDAD FUNDAMENTAL 4:

REVISIÓN BIBLIOGRÁFICA

EQUIPO 05

MATRÍCULA | NOMBRE | PE
1966252 | CONSTANTE MALDONADO KEVIN YAIR | IMC
1964189 | MORALES ESCOBEDO ERICK RUBEN | IMC
2078113 | SANCHEZ MELENDEZ OSWALDO | IMC

TÍTULO DEL PROYECTO:

“IoT Autonomous Fire Detection and Firefighting Robot”

ASESOR: DR. ERICK DE JESÚS ORDAZ RIVAS

GRUPO: 008 HORA: MARTES V1

SEMESTRE: ENERO - JUNIO 2025

FECHA DE ENTREGA: 13 DE FEBRERO DEL 2025

CIUDAD UNIVERSITARIA A 13 DE FEBRERO DEL 2025

# Objetivo

El estudiante será capaz de investigar y analizar antecedentes técnicos y científicos relevantes al tema del proyecto, construyendo un marco teórico sólido que respalde la propuesta del sistema mecatrónico a desarrollar.

# Resumen

Esta revisión bibliográfica se realizó con un propósito dirigido a dos enfoques principales: primero, identificar soluciones previamente desarrolladas que abordan la problemática de detección y respuesta ante incendios; segundo, analizar arquitecturas y tecnologías aplicadas en proyectos similares, aunque con diferentes propósitos, para evaluar su aplicabilidad en nuestra propuesta.

Las áreas clave investigadas abarcan tecnologías para la detección de incendios, implementación de redes IoT, sistemas de posicionamiento GPS y arquitecturas de vehículos autónomos. En particular, se exploraron enfoques innovadores para la detección temprana de incendios mediante sensores combinados, redes neuronales y algoritmos de lógica difusa, así como estrategias de navegación y control de vehículos autónomos mediante GPS para la respuesta rápida ante emergencias.

Entre los hallazgos más relevantes se destaca la importancia de diseñar sistemas robustos y eficientes que integren múltiples sensores y tecnologías avanzadas de procesamiento de datos para garantizar la fiabilidad en la detección de incendios. Además, se identificaron diversas arquitecturas de IoT para la transmisión y procesamiento de datos, resaltando la relevancia de la comunicación en tiempo real y la gestión eficiente de recursos. También se analizaron distintas estrategias de navegación autónoma que optimizan el desplazamiento de vehículos en terrenos complejos mediante algoritmos y tecnologías de geolocalización.

Esta revisión no solo proporciona un panorama integral de los avances tecnológicos en estas áreas, sino que también sirve como base para la selección de enfoques adecuados para la implementación de nuestro proyecto, alineando las mejores prácticas y soluciones innovadoras con nuestros objetivos específicos.

# Introducción

Los incendios representan una amenaza significativa tanto para el medio ambiente como para la seguridad de las personas y la infraestructura. La detección temprana y la respuesta rápida son esenciales para minimizar daños y prevenir la propagación del fuego. Esta problemática es el eje central de este proyecto, que plantea el desarrollo de un sistema inalámbrico basado en IoT para el monitoreo y detección de incendios en distintos puntos. Además, se propone el uso de un vehículo autónomo equipado con una bomba de agua para responder de manera eficiente a la emergencia y mitigar las llamas. Para ello, tanto el vehículo como los puntos de monitoreo estarán equipados con módulos GPS, lo que permitirá una navegación precisa y coordinada.

Con este proyecto en mente, se ha llevado a cabo una revisión bibliográfica con el objetivo de conocer y analizar distintos enfoques y tecnologías aplicadas a vehículos autónomos y sistemas de detección de incendios. La importancia de esta revisión radica en la posibilidad de identificar tendencias tecnológicas y evaluar la efectividad de cada enfoque, con el fin de seleccionar estrategias adecuadas para la implementación en nuestro proyecto.

Los objetivos específicos de esta investigación son:

1. Examinar distintos métodos de detección de incendios utilizados en sistemas automatizados.
2. Analizar enfoques en sistemas de vehículos autónomos que utilicen GPS.
3. Evaluar diferentes arquitecturas de solución para abordar la problemática de detección y respuesta ante incendios.

Esta revisión bibliográfica proporcionará un marco de referencia sólido para el desarrollo del sistema, asegurando que la solución adoptada sea eficiente, innovadora y técnicamente viable.

# Revisión de antecedentes

ZigBee enabled IoT based intelligent lane control system for autonomous agricultural electric vehicle application.

(Publicado en julio del 2023)

El artículo presenta el desarrollo de un mecanismo inteligente de control de carril para tractores eléctricos en India, basado en tecnologías IoT y ZigBee. La propuesta consiste en mapear el terreno como un plano cartesiano, donde en cada punto (X,Y) se instala un nodo ZigBee que transmite su posición GPS al microcontrolador del tractor. A partir de esta información, el microcontrolador define y ajusta las trayectorias de movimiento del vehículo, permitiendo una navegación autónoma dentro de un área delimitada.

Aunque esta solución está diseñada para una necesidad diferente, presenta ciertas similitudes con la que estamos planeando, ya que implementa tecnologías de manera similar. Sin embargo, también existen diferencias en su aplicación y enfoque.

Development of an Early Fire Detection Technique Using a Passive Infrared Sensor and Deep Neural Networks

(Publicado en octubre del 2022)

Este artículo presenta un método de detección de incendios en tiempo real basado en la recolección de datos de un sensor PIR. El procesamiento de estas lecturas implica una transformación avanzada mediante el uso de wavelets, seguida de la generación de imágenes en formato RGB que se utilizan como entrada para una red neuronal convolucional profunda. Esta red clasifica los datos en tres categorías: sin movimiento (fondo), movimiento humano e incendio, diferenciando entre fuegos cuasi-estáticos y en expansión.

Los resultados experimentales destacan que la arquitectura ShuffleNet obtuvo la mayor precisión de predicción con un 87.8%. Además, la estrategia en tiempo real, operando a 12 cuadros por segundo, logró una precisión del 95.34% en detección de incendios y 92.39% en detección de movimiento humano. Este artículo representa un antecedente relevante en la detección de incendios, ofreciendo una perspectiva alternativa de arquitectura basada en redes neuronales para este propósito

Smart Fire Detection and Deterrent System for Human Savior by Using Internet of Things (IoT)

(Publicado en septiembre del 2021)

El artículo presenta el desarrollo de un sistema inteligente de detección de incendios con mayor precisión que los sistemas basados en un solo sensor. Para lograrlo, propone el uso de tres sensores que trabajan en conjunto: un sensor de llama, un sensor de humo y un sensor de humedad. La combinación de estos dispositivos permite mejorar la fiabilidad en la detección de incendios y reducir falsas alarmas.

Además, el artículo plantea que los datos recopilados sean procesados mediante un sistema de lógica difusa basado en inteligencia artificial, lo que permite tomar decisiones más precisas según las condiciones del entorno.

Este enfoque representa un sistema robusto e inteligente para la detección de incendios, lo que lo convierte en un antecedente relevante para nuestro proyecto, especialmente en el desarrollo del componente de monitoreo y detección de fuego.

An autonomous ground robot to support firefighters’ intervention in indoor emergencies (Publicado el 11 de enero del 2023)

Este artículo describe un proyecto basado en la construcción de un robot terrestre autónomo capaz de obtener datos en tiempo real sobre la ubicación y el entorno de incendios en interiores, así como el desarrollo y planificación de estrategias mediante el uso de un simulador que reproduce distintos escenarios de emergencia, esto con el fin de que los equipos de intervención puedan reducir sus tiempos de exposición, lograr un mejor entendimiento de la situación y proporcionar alternativas para esquivar áreas potencialmente peligrosas.

El robot consta de una arquitectura dividida en tres niveles: el nivel 0 corresponde a la etapa de potencia, el nivel 2 a la percepción y la comunicación, y el nivel 3 está disponible para futuras implementaciones. En cuanto a la capa de alimentación y actuación, el robot consta de dos motores de corriente continua (GM25-370), alimentados por tres baterías recargables de iones de litio de 3,7 V y 12.800 mAh y una batería de litio de 5V y 10.800 mAh para la carga útil, esto controlado por un interruptor. Por otro lado, el nivel 2, contiene un controlador de motor y dos microcontroladores (Arduino UNO WiFi REV2 Y Raspberry Pi 4). La placa Arduino genera las entradas de voltaje para los motores en base a los comandos recibidos mientras que la placa Raspberry Pi 4 realiza las tomas de decisiones, el accionamiento y las comunicaciones del robot con la estación base. Por último, el nivel 2 cuenta con seis sensores ultrasónicos que cubren el perímetro del robot y dos sensores ambientales, uno para medir la temperatura del aire y la humedad relativa y el otro para determinar la calidad del aire y medir la concentración de gases mientras que en la capa 3 está preparado para integrar cámaras térmicas, entre otras funcionalidades.

Implementing a Prototype Autonomous Fire Detecting and Firefighting Robot

(Publicado el 29 de mayo del 2023)

Este artículo presenta diferentes métodos para la detección de fuego destacando el uso de sensores infrarrojos en incendios de interiores. Además, propone una alternativa para el uso de redes neuronales convolucionales para el procesamiento de imágenes y detectar los incendios con ayuda de un sistema de visión.

El robot consta de tres sensores infrarrojos colocados en la parte lateral izquierda, derecha y superior, en conjunto con una bomba activada por un servomotor que accionará una inclinación hacia la dirección del incendio. En cuanto a la parte de actuación, el movimiento del robot está basado en dos motores DC conectados a un controlador, el cual se encarga de enviar señales para posicionar al robot en la dirección del incendio detectada por el sensor, posteriormente, se envía una señal para activar la bomba y apagar el incendio.

Diseño y prototipado de un robot explorador que soporte las actividades de los bomberos

(Publicado el 13 de diciembre del 2015)

El documento describe el diseño y el prototipo de una plataforma robótica (FireBot) cuyo sistema mecánico está basado en un sistema de orugas y una suspensión rocker-bogie. Además, cuenta con tres sensores de temperatura por infrarrojo para identificar zonas calientes, dos cámaras de resolución para tener un mayor control de la escena y una tarjeta de desarrollo ODROID-XU3 Lite capaz de procesar imágenes de video para identificar fuego y alertar al controlador, la transmisión de vídeo y el control manual se realiza inalámbricamente (WiFi).

En resumen, FireBot es una plataforma diseñada para que sea capaz de acceder a espacios habitados como edificios y bodegas, planteando movimientos como subir escaleras, evitar obstáculos en el suelo y ser de un tamaño adecuado para pasar por lugares estrechos como puertas y pasillos.

Mobile robotic platform IoT-based for LP gas detection

(Publicado el 17 de julio del 2023)

Este artículo presenta el diseño de un robot móvil de bajo costo que utiliza plataformas IoT y diversos sensores que le permiten manejar de forma autónoma entornos controlados en los que al mismo tiempo pueden detectar la existencia de fugas de gas de licuado de petróleo. La plataforma en la nube permite almacenar los datos del sensor de gas LP y del GPS para la ubicación del robot, así como la transmisión de comandos entre el servidor y el vehículo mediante el uso de una aplicación móvil. El robot está constituido por una cámara que permite obtener video en tiempo real y monitorear el ambiente de inspección de manera remota.

En resumen, el robot abarca tareas como la detección de gas, evasión de obstáculos y el registro de ubicación GPS. Con respecto al hardware, el robot consta de un sensor ultrasónico, un sensor MQ-6 y un módulo GPS, los cuales se comunican a un ESP32, asimismo, las lecturas son enviadas y almacenadas en una base de datos Firebase. Esto con la finalidad de detectar una fuga de gas y enviar la ubicación a una base de datos IoT para que pueda ser consultada por una aplicación móvil.

Implementación de un prototipo de monitoreo para la visualización en tiempo real de vehículos utilizando GPS y ESP32

(Publicado el 13 de septiembre de 2024)

El artículo describe una solución para la supervisión continua de la ubicación de distintos vehículos, como prototipo se presenta un robot equipado con un ESP32 y un módulo GPS para rastreo en tiempo real. A través de una base de datos desde la plataforma ThingSpeak se procesaron las coordenadas con la ubicación del vehículo (latitud, longitud, velocidad y altura). Algunos de los aspectos más destacados en este proyecto son la eficiencia energética del ESP32, la interactividad con el dashboard web y la precisión de la ubicación con el GPS.

IoT Technology Based Fire-Fighter Robot

(Publicado en julio de 2020)

El artículo presenta un robot bombero basado en IoT diseñado para detectar y extinguir incendios de manera eficiente, reduciendo los riesgos para los bomberos en situaciones peligrosas. El sistema combina operación autónoma y control remoto, lo que permite intervenir en diferentes escenarios según la disponibilidad de un operador. El robot puede operar en dos modos. En el modo autónomo, si no recibe instrucciones en un tiempo determinado, actúa por sí mismo utilizando sensores y procesamiento de imágenes para localizar y extinguir el fuego. En el modo manual, un operador puede controlarlo de forma remota a través de una aplicación, visualizando el entorno mediante una cámara integrada y eligiendo el mejor método de extinción.

El núcleo del sistema es un Raspberry Pi 3 B+, que gestiona la comunicación con el operador a través de Wi-Fi y permite la transmisión en vivo de la zona afectada. Además, el robot está equipado con sensores de llama para detectar incendios y sensores ultrasónicos para evitar obstáculos. Cuando el sensor de llama detecta fuego, envía una alerta a la aplicación del operador. Si el operador está disponible, puede manejar el robot y decidir cómo extinguir el incendio. Si no hay respuesta, el robot se desplaza de forma autónoma hacia la zona afectada y aplica el método de extinción adecuado. Para determinar la ubicación exacta del fuego, el robot emplea algoritmos de procesamiento de imágenes con OpenCV.

IoT based guided fire fighting vehicle

(Publicado en mayo de 2022)

El artículo presenta un vehículo bombero guiado basado en IoT, diseñado para detectar y extinguir incendios en entornos domésticos e industriales, reduciendo el riesgo para los bomberos. Este sistema combina la detección automática de incendios con el control remoto por parte del usuario, permitiéndole dirigir el vehículo hacia la zona afectada y gestionar el proceso de extinción de manera eficiente. El funcionamiento del sistema inicia cuando el sensor de llama detecta un incendio y envía una alerta al usuario a través de un módulo GSM. A partir de esta notificación, el operador puede guiar el vehículo hasta la ubicación del fuego utilizando la aplicación Blynk y una cámara integrada que transmite en tiempo real. Una vez en posición, el usuario puede ajustar la dirección y la intensidad del chorro de agua mediante un servomotor conectado a la manguera de extinción.

El prototipo está basado en un Arduino UNO, acompañado de un módulo ESP32-CAM para la transmisión de video en vivo y un sensor ultrasónico para evitar obstáculos. La comunicación con el usuario se establece a través de IoT, permitiendo el control remoto desde cualquier parte del mundo. Además, el sistema incluye un sensor de nivel de agua para asegurar un suministro adecuado durante la extinción del incendio y un módulo GSM como respaldo en caso de fallos en la conexión a Internet.

Análisis Comparativo

Los artículos revisados presentan diversas aproximaciones a la detección y extinción de incendios mediante robots autónomos y sistemas IoT. Algunas soluciones están enfocadas en la detección temprana de fuego utilizando sensores y redes neuronales, mientras que otras proponen el uso de vehículos autónomos equipados con GPS para una mejor movilidad y localización en espacios grandes.

Entre las soluciones basadas en IoT y sensores, destacan los estudios "Smart Fire Detection and Deterrent System for Human Savior by Using IoT" (2021) y "Development of an Early Fire Detection Technique Using a Passive Infrared Sensor and Deep Neural Networks" (2022), que emplean sensores de llama, humo y humedad, así como sensores PIR combinados con redes neuronales para mejorar la precisión en la detección de incendios. Sin embargo, estos sistemas son principalmente pasivos, ya que se limitan al monitoreo y detección sin capacidad de intervención autónoma.

En cuanto a los robots autónomos para la extinción de incendios, los proyectos "Implementing a Prototype Autonomous Fire Detecting and Firefighting Robot" (2023) y "An autonomous ground robot to support firefighters’ intervention in indoor emergencies" (2023) presentan enfoques en los que los robots móviles pueden detectar incendios y desplazarse de forma independiente. Mientras que el primero se basa en sensores infrarrojos, el segundo integra procesamiento de imágenes y múltiples sensores ambientales para una mejor evaluación del entorno.

Algunas soluciones incluyen sistemas con GPS para mejorar la navegación, como el "ZigBee enabled IoT based intelligent lane control system for autonomous agricultural electric vehicle application" (2023), que utiliza nodos ZigBee para mapear el terreno y guiar el vehículo. De manera similar, "Mobile robotic platform IoT-based for LP gas detection" (2023) combina IoT y GPS para registrar la ubicación del robot mientras detecta fugas de gas.

Por otro lado, existen sistemas que combinan el control remoto y la operación autónoma, como "IoT Technology Based Fire-Fighter Robot" (2020) y "IoT based guided fire fighting vehicle" (2022). Estas soluciones emplean cámaras y aplicaciones móviles para que un operador pueda controlar el sistema de extinción a distancia, logrando una mayor eficiencia y adaptabilidad en distintos escenarios de incendio.

Ventajas y Desventajas

Tecnología | Ventajas | Desventajas
Sensores de fuego y humo | Detección temprana y reducción de falsas alarmas | No pueden actuar sobre el incendio
Redes neuronales | Alta precisión en clasificación de incendios | Alto costo computacional
Vehículos autónomos con sensores infrarrojos | Navegación independiente | Limitaciones sin GPS
GPS y ZigBee | Precisión en navegación | Requiere infraestructura adicional
Control remoto por IoT | Facilita monitoreo en tiempo real | Depende de conectividad estable

Este proyecto se distingue por la integración de un sistema de navegación GPS, combinando con modelos de inteligencia artificial para lograr una navegación autónoma y una detección más precisa. Además, optimiza la extinción del fuego mediante estrategias adaptativas. La incorporación de tecnología IoT garantiza una mejor coordinación en tiempo real entre el robot y el desarrollo del incendio.

# Conclusiones

Constante Maldonado Kevin Yair

Una vez que se ha llevado a cabo la búsqueda de antecedentes, se puede concluir que existe una base sólida de proyectos que utilizan el concepto del robot contraincendios, sin embargo, cada uno de ellos se han focalizado en alguna aplicación específica, además de utilizar tecnologías específicas como lo son Zigbee. Sin duda, esta búsqueda nos ha permitido analizar el estado actual del desarrollo que se tiene de los robots contraincendios, de esta manera, podemos observar aquellas áreas de oportunidad que se han presentado en los diversos proyectos y acatarlas para proponer alguna solución que le dé fin a estas limitaciones.

Morales Escobedo Erick Rubén

Tras realizar la investigación, se ha concluido que la detección temprana de incendios, la presencia de obstáculos, la navegación autónoma y el procesamiento de datos pueden representar desafíos significativos para cumplir con el propósito del proyecto. Se han encontrado documentos importantes que abordan ciertos obstáculos que podrían surgir en el futuro, como la precisión en las coordenadas del GPS, el rango de detección de las llamas, el manejo de la trayectoria del robot, la selección del controlador, y los sistemas de percepción, sensores y actuadores adecuados. Por último, contar con conocimientos sobre el uso de tecnologías emergentes como el Internet de las Cosas (IoT) y las redes neuronales aumenta las expectativas para desarrollar una alternativa innovadora ante la problemática inicialmente propuesta.

Sánchez Meléndez Oswaldo

Tras realizar esta revisión bibliográfica, pude apreciar que existen diversos desarrollos enfocados en abordar la problemática que buscamos resolver, lo que nos motiva a desarrollar una propuesta propia que aporte valor y resultados relevantes. Además, fue de gran utilidad analizar arquitecturas de vehículos autónomos, sistemas inteligentes para la detección de incendios y tecnologías IoT, ya que nos brindan una base sólida para conceptualizar la arquitectura de nuestro proyecto. En general, considero que la revisión estuvo bien orientada, ya que abarcamos aspectos clave como la navegación autónoma, la comunicación mediante IoT y la detección de incendios, todos fundamentales para el desarrollo de nuestra solución.

# Referencias

- Azeta, J., Ayoade, I., Nwakanma, C., & Akande, T. (2023). Implementing a Prototype Autonomous Fire Detecting and Firefighting Robot. MDPI. https://doi.org/10.20944/preprints202305.2010.v1
- Cortes, Á. J. B., Cruz, E. M., Barrientos, A. G., Jiménez, N. P., Almaraz, M. X. H., Flores, A. M., & Marroquín, A. (2023). Mobile robotic platform IoT-based for LP gas detection. LACCEI. https://doi.org/10.18687/laccei2023.1.1.1470
- Laínez Apolinario, W. P., & Navarrete Buste, G. E. (2024). Implementación de un prototipo de monitoreo para la visualización en tiempo real de vehículos utilizando GPS y ESP32 (Tesis de pregrado, Universidad Politécnica Salesiana). Repositorio Digital UPS. https://dspace.ups.edu.ec/bitstream/123456789/29212/4/UPS-GT005841.pdf
- López-Prieto, J. F., Quijano, C. E., Moncayo, R. A., Piedrahita, J. H., Jiménez, J. D., Navarro, N. D., & Angarita, I. I. (2015). Diseño y prototipado de un robot explorador que soporte las actividades de los bomberos. Memorias.
- Palaniappan, A., Muthiah, R., & Sundaram, M. T. (2023). ZigBee enabled IoT based intelligent lane control system for autonomous agricultural electric vehicle application. SoftwareX, 23, 101512.
- Raafeek, A. R. M., Satheeskanth, N., Joy Mathavan, J., & Kunaraj, A. (2022). IoT based guided fire fighting vehicle. IOP Conference Series: Materials Science and Engineering, 1258, 012062. https://doi.org/10.1088/1757-899X/1258/1/012062
- Rehman, A., Qureshi, M. A., Ali, T., Irfan, M., Abdullah, S., Yasin, S., ... & Węgrzyn, M. (2021). Smart fire detection and deterrent system for human savior by using internet of things (IoT). Energies, 14(17), 5500.
- Talavera, N. F., Roldán‐Gómez, J. J., Martín, F., & Rodriguez‐Sanchez, M. C. (2023). An autonomous ground robot to support firefighters’ interventions in indoor emergencies. Journal Of Field Robotics, 40(3), 614-625. https://doi.org/10.1002/rob.22150
- Vyshnavi, M. B., Satheesh, A., Suresh, S. S., & Manikandan, L. C. (2020). IoT Technology Based Fire-Fighter Robot. International Journal of Scientific Research in Computer Science, Engineering and Information Technology, 6(3), 934-941. https://doi.org/10.32628/CSEIT2063187
- Xavier, K. L. B. L., & Nanayakkara, V. K. (2022). Development of an early fire detection technique using a passive infrared sensor and deep neural networks. Fire oTechnology, 58(6), 3529-3552.

# Anexos

## Repartición de tareas del equipo

- Kevin Yair Constante Maldonado: Búsqueda de antecedentes relacionados con robots autónomos contraincendios con la capacidad de cambiar entre modos automáticos y manuales. Además de realizar el análisis comparativo entre todos los antecedentes recabados.
- Erick Rubén Morales Escobedo: Búsqueda de artículos relacionados con el diseño y prototipado de robots autónomos para combatir incendios y métodos para la detección de incendios (sensores UV, procesamiento de imágenes, sensores de gas, etc.).
- Oswaldo Sánchez Meléndez: Redacción del resumen e introducción y búsqueda de antecedentes sobre el uso de tecnologías IoT en vehículos autónomos y sobre sistemas de detección de incendios.

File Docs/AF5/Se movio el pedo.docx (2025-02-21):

FIME UANL (@FIME_Oficial) | Twitter
La UANL será sede de la Universiada Nacional 2015 | Comisión ...

UNIVERSIDAD AUTÓNOMA DE NUEVO LEÓN

FACULTAD DE INGENIERÍA

MECÁNICA Y ELÉCTRICA

PROYECTO DE IMTC

ACTIVIDAD FUNDAMENTAL 5:

ANTEPROYECTO

EQUIPO 05

MATRÍCULA | NOMBRE | PE
1966252 | CONSTANTE MALDONADO KEVIN YAIR | IMC
1964189 | MORALES ESCOBEDO ERICK RUBEN | IMC
2078113 | SANCHEZ MELENDEZ OSWALDO | IMC

TÍTULO DEL PROYECTO:

“IoT Autonomous Fire Detection and Firefighting Robot”

ASESOR: DR. ERICK DE JESÚS ORDAZ RIVAS

GRUPO: 008 HORA: MARTES V1

SEMESTRE: ENERO - JUNIO 2025

FECHA DE ENTREGA: 18 DE FEBRERO DEL 2025

Resumen (Oswaldo)

Robot contra incendios y estaciones de monitoreo que una vez que detecten incendios manden los datos a un server y ese server los envié a el robot, y el robot defina la trayectoria para ir al lugar y activar un mecanismo para mitigar el incendio para apagar el incendio.

Introducción (Oswaldo)

Planteamiento del problema (Pendiente)

Objetivos

Robot autónomo que sea capaz de mitigar un incendio.

Electrónica: sensores. Modulos, pcbs etc. Gps, (Erick)

Control: Algoritmo (Oswaldo)

Mecánico: Estructura del carrito y mecanismo de mitigación de incendio, bomba de agua, (Kevin)

Alcance

El carrito se podrá mover libremente en un espacio sin interferencias, desarrollando la trayectoria más optima a través del cálculo entre los datos recibidos por el GPS.

Los módulos de monitoreo estarán compuestos por sensores de flama, humedad y humo y temperatura. A través de un algoritmo serán capaces de definir si existe o no un incendio.

Existirá la funcionalidad de que los módulos de monitoreo sean capaces de enviar sus datos a un servicio cloud (firebase, azure,aws, etc) y aqui se procesen y se envien al robot y posteriormente actúe el robot.

Los módulos podrán ubicarse en diferentes zonas, es decir, pueden ser móviles.

Los módulos de monitoreo solo escribirán datos al servidor cuando hayan detectado un evento. El procesamiento de datos será en el microcontrolador del módulo.

El robot será capaz de esquivar un objeto si sus sensores lo detectan. Y posteriormente continuar con la trayectoria.

El robot será capaz de mitigar incendios de demostración.

El robot tendrá un mecanismo con una bomba de agua para poder mitigar el incendio.

Fuera de alcance

El robot no será capaz de identificar entradas, salidas, etc. Solamente será capaz de esquivar objetos. (Desarrollar)

El robot no será capaz de manejar prioridades en caso de que ocurran 2 eventos a la vez, el orden será FIFO (PEPS).

El robot contará con un tanque de agua que requerirá intervención manual para su rellenado.

El robot no contará con visión artificial para localizar con precisión el incendio. (Desarrollar)

Justificación técnica (Chatgpt)

Metodología

Definición del proyecto objetivos, anteproyecto, etc. Desarrollar 10 feb al 16 feb

Diseño y Construcción de la estructura mecanica del robot. 16 feb al 10 de marzo

Diseño y Construcción de la estructura mecanica de los módulos de monitoreo. 16 feb al 10 de marzo

Diseño e implementación de la electrónica en el robot. 16 feb al 10 de marzo

Diseño e implementación de la electrónica de los módulos de monitoreo 16 feb al 10 de marzo

Definición y desarrollo de algoritmos de control. 16 feb al 23 feb

Planteamiento

Desarrollo

Codificación

Validación y correcciones

Diseño e implementación del algoritmo de procesamiento de datos de los módulos de monitoreo para la detección de incendios.

Establecer la comunicación entre los modulos de monitoreo, el servicio nube y el robot.

Diseñar e implementar el algoritmo para el desarrollo de trayectorias del robot.

Diseñar e implementar el algoritmo para la evasión de objetos.

Diseñar e implementar el algoritmo para mitigación de incendios.

Validación y verificación.

Mandar tabla.

Cronograma

Plan inicial de recursos

- Descripción:
  - Desglose preliminar de los recursos necesarios:
    - Materiales: Componentes y herramientas clave.
    - Presupuesto: Estimación inicial de costos totales.
    - Infraestructura: Espacios, software o equipos necesarios.

Materiales:

Se plantea hacer uso de diversos materiales de fabricación como madera, impresión 3D, metales, etc. Para realizar la estructura mecánica del robot autonómo, Por otro lado, en la electrónica para la etapa de sensores se van a requerir sensores de proximidad (Ultrasonicos), sensores de temperatura, sensores de C02, Modulos GPS.

Para la etapa de procesamiento se va a requerir el uso de varios microcontroladores ESP32, modulos L298D para el cambio de giro de los motores. Para la etapa de actuadores se va a requerir motores para el movimiento del carrito, una bomba de agua, tanques de 12g de C02 para dar presión al agua. Algún tanque para almacenar agua.

Conclusión

Referencias

Anexos

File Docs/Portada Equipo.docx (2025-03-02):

FIME UANL (@FIME_Oficial) | Twitter
La UANL será sede de la Universiada Nacional 2015 | Comisión ...

UNIVERSIDAD AUTÓNOMA DE NUEVO LEÓN

FACULTAD DE INGENIERÍA

MECÁNICA Y ELÉCTRICA

PROYECTO DE IMTC

ACTIVIDAD FUNDAMENTAL 4:

REVISIÓN BIBLIOGRÁFICA

EQUIPO 05

MATRÍCULA | NOMBRE | PE | #LISTA
1966252 | CONSTANTE MALDONADO KEVIN YAIR | IMC
1964189 | MORALES ESCOBEDO ERICK RUBEN | IMC
2078113 | SANCHEZ MELENDEZ OSWALDO | IMC

DOCENTE: DR. ERICK DE JESÚS ORDAZ RIVAS

GRUPO: 008 HORA: MARTES V1

SEMESTRE: ENERO - JUNIO 2025

CIUDAD UNIVERSITARIA A 13 DE FEBRERO DEL 2025

# Objetivo

XXXXX

# Marco teórico

XXX

# Procedimiento

XXX

# Evidencias

XXX

# Conclusiones

Constante Maldonado Kevin Yair

XXXXX

Morales Escobedo Erick Rubén

XXXXXX

Sánchez Meléndez Oswaldo

XXX

# Referencias

XXX

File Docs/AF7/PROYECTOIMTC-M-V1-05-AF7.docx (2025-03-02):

FIME UANL (@FIME_Oficial) | Twitter
La UANL será sede de la Universiada Nacional 2015 | Comisión ...

UNIVERSIDAD AUTÓNOMA DE NUEVO LEÓN

FACULTAD DE INGENIERÍA

MECÁNICA Y ELÉCTRICA

PROYECTO DE IMTC

ACTIVIDAD FUNDAMENTAL 7:

DISEÑO DE CONTROL Y/O ALGORÍTMICO

EQUIPO 05

MATRÍCULA | NOMBRE | PE
1966252 | CONSTANTE MALDONADO KEVIN YAIR | IMC
1964189 | MORALES ESCOBEDO ERICK RUBEN | IMC
2078113 | SANCHEZ MELENDEZ OSWALDO | IMC

TÍTULO DEL PROYECTO:

“IoT Autonomous Fire Detection and Firefighting System”

ASESOR: DR. ERICK DE JESÚS ORDAZ RIVAS

GRUPO: 008 HORA: MARTES V1

SEMESTRE: ENERO - JUNIO 2025

FECHA DE ENTREGA: 04 DE MARZO DEL 2025

CIUDAD UNIVERSITARIA A 04 DE MARZO DEL 2025

# Introducción

TEXTO.

# Objetivo del Diseño de Control/Algoritmo

TEXTO.

# Diseño de Control y/o Algoritmo

TEXTO.

# Simulaciones y Resultados

TEXTO.

# Especificaciones Técnicas

TEXTO.

# Conclusión

Morales Escobedo Erick Rubén

TEXTO.

Sánchez Meléndez Oswaldo

TEXTO.

Constante Maldonado Kevin Yair

TEXTO.

# Referencias

- TEXTO

# Anexos

## Repartición de tareas del equipo

Oswaldo Sánchez Meléndez: XXX

Erick Rubén Morales Escobedo: XXX

Kevin Yair Constante Maldonado: XXX

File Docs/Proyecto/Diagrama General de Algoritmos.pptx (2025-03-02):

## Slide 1

IoT Autonomous Fire Detection and Firefighting System

Servicio en la nube

1. Escuchar continuamente por nueva información proveniente de los módulos de detección.
2. En el momento en el que reciba nueva información, enviarla al vehículo.


Vehículo autónomo de respuesta

1. Escuchar continuamente por nueva información proveniente del servicio en la nube.
2. En el momento en el que reciba nueva información, dirigirse a la localización GPS recibida (mientras esquiva obstáculos).
3. Mitigar el incendio.
4. Regresar a un punto HOME.


Módulos de detección

1. Leer continuamente los datos de los sensores.
2. Procesar los datos para definir si existe un incendio.
3. En el momento en el que detecte un incendio, enviar la señal de alerta a la nube, junto con las lecturas de los sensores y la información del GPS.


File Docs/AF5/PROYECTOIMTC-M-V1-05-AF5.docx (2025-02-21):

FIME UANL (@FIME_Oficial) | Twitter
La UANL será sede de la Universiada Nacional 2015 | Comisión ...

UNIVERSIDAD AUTÓNOMA DE NUEVO LEÓN

FACULTAD DE INGENIERÍA

MECÁNICA Y ELÉCTRICA

PROYECTO DE IMTC

ACTIVIDAD FUNDAMENTAL 5:

ANTEPROYECTO

EQUIPO 05

MATRÍCULA | NOMBRE | PE
1966252 | CONSTANTE MALDONADO KEVIN YAIR | IMC
1964189 | MORALES ESCOBEDO ERICK RUBEN | IMC
2078113 | SANCHEZ MELENDEZ OSWALDO | IMC

TÍTULO DEL PROYECTO:

“IoT Autonomous Fire Detection and Firefighting System”

ASESOR: DR. ERICK DE JESÚS ORDAZ RIVAS

GRUPO: 008 HORA: MARTES V1

SEMESTRE: ENERO - JUNIO 2025

FECHA DE ENTREGA: 18 DE FEBRERO DEL 2025

CIUDAD UNIVERSITARIA A 18 DE FEBRERO DEL 2025

# Resumen

Este proyecto tiene como objetivo el desarrollo de un sistema automatizado para la detección y respuesta ante incendios, compuesto por dos componentes principales: módulos de monitoreo y un vehículo de respuesta autónomo. Los módulos de monitoreo están diseñados para detectar incendios mediante sensores que monitorean variables clave, mientras que el vehículo autónomo se encarga de desplazarse hacia la localización del incendio y extinguirlo sin intervención humana.

Los objetivos preliminares incluyen el desarrollo e implementación de los componentes mecatrónicos necesarios para el funcionamiento del sistema, abarcando áreas como la mecánica, la electrónica y el control. Además, se busca integrar estos componentes en un sistema automatizado que permita la operación conjunta de los módulos de monitoreo y el vehículo autónomo.

La justificación principal de este proyecto radica en que el desarrollo de una solución completamente autónoma que elimine la necesidad de intervención humana resulta en una propuesta de valor significativa. Al automatizar la detección y la respuesta ante incendios, se espera acelerar los tiempos de reacción, reduciendo los daños y salvaguardando la integridad de las personas.

Al finalizar el prototipo, se espera que los módulos sean capaces de detectar incendios con alta precisión y enviar la señal correspondiente a la nube, que alertará al vehículo. Además, el vehículo será capaz de recibir la señal de alerta y desplazarse de manera autónoma hasta el incidente, esquivando obstáculos sencillos en un ambiente controlado.

# Introducción

Los incendios representan una amenaza significativa tanto para el medio ambiente como para la seguridad de las personas y la infraestructura. La detección temprana y la respuesta rápida son esenciales para minimizar daños y evitar la propagación del fuego. Esta problemática cobra especial relevancia en la actualidad, donde factores como el aumento en la temperatura global y la creciente cantidad de dispositivos eléctricos conectados han incrementado la incidencia de incendios. Este proyecto aborda dicha problemática mediante el desarrollo de un sistema autónomo de detección y respuesta ante incendios.

El objetivo principal de este anteproyecto es delimitar los objetivos, alcances y actividades del proyecto, así como los recursos humanos, materiales y económicos necesarios para su ejecución dentro del marco del curso.

# Planteamiento del problema

Los incendios representan una de las amenazas más graves para las infraestructuras, los ecosistemas y la salud humana. La detección tardía y la falta de una respuesta inmediata dificultan enormemente la contención del fuego, lo que provoca daños irreparables que podrían haberse evitado. Aunque existen sistemas de detección y extinción de incendios en diversas instalaciones, muchos de estos dependen de sensores individuales o requieren intervención humana para su activación, lo que genera retrasos en la respuesta y limita su efectividad en situaciones de emergencia.

Las principales causas de los incendios incluyen factores naturales, como el cambio climático y las sequías prolongadas, así como factores humanos, tales como fallas en instalaciones eléctricas, negligencias o incendios provocados. La falta de automatización y conectividad en los sistemas tradicionales de detección de incendios es uno de los principales obstáculos, ya que reduce significativamente la eficiencia en la prevención y mitigación de los daños, especialmente en zonas de difícil acceso o cuando la intervención humana es limitada.

Este proyecto propone una solución innovadora que integra la detección automática de incendios y una respuesta autónoma mediante un vehículo equipado con capacidades de navegación. El sistema diseñado permite la detección temprana de incendios a través de módulos de monitoreo que analizan continuamente variables clave como la temperatura y los niveles de gases. En caso de detectar un incendio, el sistema no solo informa la situación, sino que activa un agente autónomo capaz de moverse hacia la localización del fuego y extinguirlo sin intervención humana directa. De esta manera, se optimiza la rapidez y precisión de la respuesta ante situaciones de emergencia, mejorando la seguridad y reduciendo los daños ocasionados por los incendios.

# Objetivos

## Objetivo General

Desarrollar un sistema autónomo de detección y respuesta ante incendios, compuesto por módulos de monitoreo y un vehículo de respuesta capaz de mitigar las llamas de manera eficiente.

## Objetivos Específicos

Electrónico: 1) Diseñar un sistema de detección de incendios basado en sensores de temperatura, humo y llama; 2) Integrar comunicación inalámbrica para el envío de alertas y monitoreo remoto; 3) Desarrollar un sistema de movilidad que permita al robot desplazarse de forma autónoma; 4) Establecer una unidad de control para el procesamiento de datos provenientes de los sensores; 5) Implementar un sistema de control para la activación y operación de la bomba de agua; 6) Implementar estrategias para la evasión de obstáculos; 7) Utilizar un sistema de alimentación eficiente que garantice un funcionamiento prolongado.

Control: 1) Desarrollar un algoritmo de procesamiento de datos para las lecturas de los módulos que determine la presencia de un incendio; 2) Integrar algoritmos de comunicación para la transmisión de datos desde los módulos hacia la nube y desde la nube hacia el vehículo; 3) Desarrollar un algoritmo de navegación autónoma para el vehículo, incorporando la capacidad de evasión de obstáculos; 4) Implementar un algoritmo de control para la activación y operación de la bomba de agua.

Mecánico: 1) Diseñar la estructura del robot autónomo considerando resistencia mecánica, estabilidad y capacidad de carga; 2) Desarrollar un mecanismo de mitigación de incendios que permita la dispersión de agua; 3) Garantizar la hermeticidad de la estructura del carrito para proteger la electrónica ante condiciones adversas y exposición al agua.

# Alcance

## Características del sistema

Funcionalidad | Descripción
Movilidad y Navegación del Robot | - El robot se moverá libremente en un espacio sin interferencias - Utilizará datos de GPS para calcular la trayectoria óptima hacia el punto de incendio. - Será capaz de esquivar obstáculos y continuar con su destino previamente programado. - No será capaz de identificar entradas, salidas o caminos específicos, solo esquivará objetos detectados a cierta distancia.
Módulos de monitoreo | - Equipados con sensores de flama, humedad, humo y temperatura. - Su funcionamiento consta de un algoritmo de detección de incendios. - Serán capaces de enviar datos a un servicio cloud (Azure, Firebase, AWS, etc) - Solo enviarán datos al servidor cuando detecten un evento relevante. - El procesamiento de datos se realizará en el microcontrolador del módulo.
Comunicación y Procesamiento de Datos | - Los datos enviados por los módulos serán procesados en la nube. - El servidor enviará instrucciones al robot para actuar en caso de confirmar un incendio. - El robot seguirá un esquema FIFO (Primero en Entrar, Primero en Salir) en caso de múltiples eventos simultáneos.
Sistema de Mitigación de Incendios | - El robot contará con un mecanismo con bomba de agua para mitigar incendios. - Será capaz de responder ante incendios de demostración. - Dispondrá de un tanque de agua que requerirá de intervención manual para su rellenado.

## Limitaciones y Alcances

- El robot no identificará entradas, salidas o rutas predefinidas, solo esquivará obstáculos.
- En caso de múltiples eventos simultáneos, el robot no ejecutará las acciones por prioridad, seguirá el orden FIFO.
- El sistema no contará con visión artificial como método para localizar el incendio.
- El robot no será capaz de recargar automáticamente su suministro de agua, requerirá intervención manual.
- El prototipo estará diseñado para operar en entornos con condiciones simuladas.
- No incluirá un sistema de recarga automática de energía, dependerá de mantenimiento manual.
- El sistema no cuenta con la capacidad de identificar materiales inflamables o evaluar riesgos adicionales en la zona del incendio.
- No contará con capacidades de comunicación en tiempo real en caso de pérdida con conexión con la nube.

# Justificación técnica

La detección tardía de incendios y la falta de una respuesta inmediata para mitigarlos representan una de las problemáticas más preocupantes en el diseño de infraestructuras modernas. Es crucial que estas estructuras sean seguras y cuenten con planes de emergencia altamente eficientes. Aunque actualmente existen sistemas de detección de incendios y planes de contingencia, la mayoría de ellos requieren la intervención de personal, lo que aumenta el riesgo de que se produzcan eventos más catastróficos.

La integración de tecnologías como el Internet de las Cosas (IoT) aporta grandes ventajas para detectar incendios a tiempo y responder de manera inmediata. Gracias al análisis de datos en tiempo real, permite identificar focos de incendio con rapidez y mejorar la capacidad de reacción. Además, hace posible una monitorización constante del entorno y de los factores que influyen en la propagación del fuego. Con estas capacidades, el IoT no solo fortalece la seguridad de las instalaciones, si no que también la hace más eficiente ante situaciones de emergencia.

Por otra parte, la incorporación de un sistema de posicionamiento global (GPS) ofrece la posibilidad de localizar incendios con precisión, optimización la planificación y ejecución de estrategias de mitigación más efectivas. Además, esta tecnología abre la puerta al desarrollo de robots con navegación autónoma, capaces de desplazarse durante un incendio sin necesidad de intervención humana.

Con ayuda de estas tecnologías, se busca desarrollar un sistema autónomo de detección y respuesta ante incendios. Este sistema utilizará módulos de monitoreo distribuidos de manera remota, capaces de detectar un incendio y enviar su ubicación a un agente extintor autónomo (robot) quien procederá a mitigarlos sin necesidad de intervención humana.

Para garantizar que el robot pueda cumplir su objetivo sin interrupciones, es necesario incluir sensores de proximidad para detectar obstáculos que puedan intervenir en su trayectoria y así, desplazarse de manera eficiente, evitando colisiones con objetos, colisiones o personas.

Es importante destacar que existen otras tecnologías como la visión artificial y las redes neuronales que podrían optimizar aún más el funcionamiento del sistema. No obstante, la solución propuesta es suficientemente robusta para abordar la problemática en esta fase de prototipado. A medida que el proyecto avance, se podrán incorporar mejoras y actualizaciones para su implementación a nivel industrial o en sectores públicos.

En resumen, la propuesta busca reducir significativamente la exposición humana a situaciones de alto riesgo. Esta innovación tiene como objetivo mejorar la prevención y el control de incendios de manera más efectiva, contribuyendo a la protección de las personas y el medio ambiente, y minimizando el impacto de eventos catastróficos.

# Metodología

Para el desarrollo de la parte de control del proyecto, usaremos un modelo similar al modelo en cascada de desarrollo de software, específicamente estará dividido en 4 fases: a) Análisis – planificación, análisis y especificación de los requisitos; b) Diseño – diseño y especificación del sistema o algoritmo; c) Implementación – codificación; d) Validación y mantenimiento – integración, pruebas y correcciones.

1. Definición del proyecto, objetivos, presupuestos, metodología y planificación de actividades. (10/02 – 16/02)
2. Diseño y Construcción de la estructura mecánica del robot. (16/02 – 10/03)
3. Diseño y Construcción de la estructura mecánica de los módulos de monitoreo. (16/02 – 10/03)
4. Diseño e implementación de la electrónica en el robot. (16/02 – 10/03)
5. Diseño e implementación de la electrónica de los módulos de monitoreo (16/02 – 10/03)
6. Analizar y definir los algoritmos de control y procesos de comunicación necesarios, así como las tecnologías que se utilizarán y cómo se integrarán. (18/02 – 03/03)
7. Establecer la comunicación entre los módulos de monitoreo, el servicio en la nube y el robot, asegurando la transferencia eficiente de datos y señales de alerta. (04/03 – 10/03)
8. Validación de la integración del sistema mecánico y electrónico del robot. (08/03 – 10/03)
9. Diseñar e implementar el algoritmo de navegación para que el robot se desplace de su ubicación hasta el incendio de manera autónoma. (11/03 – 14/04)
10. Diseñar e implementar el algoritmo de procesamiento de datos de los módulos de monitoreo para detectar incendios. (18/03 – 14/04)
11. Diseñar e implementar el algoritmo de evasión de obstáculos. (18/03 – 07/04)
12. Diseñar e implementar el algoritmo de mitigación de incendios. (08/04 – 14/04)
13. Integración de los algoritmos y procesos de comunicación. (15/04 – 21/04)
14. Validación, pruebas y mantenimiento de la integración. (22/04 – 28/04)

# Cronograma

A continuación, se adjunta un enlace para ver el cronograma del proyecto.

Cronograma Proyecto IMTC.xlsx (https://uanledu-my.sharepoint.com/:x:/g/personal/oswaldo_sanchezm_uanl_edu_mx/ESwNMjYDVylEjDmnB9kT1wIB28-HPDT0VjHCXzPO6kLWsw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)

# Plan inicial de recursos

A continuación, se muestra un estimado preliminar de los componentes a adquirir, así como su cantidad y costo total.

Concepto | Precio por unidad | Unidades | Cantidad Total
ESP32 WiFi | $ 162 | 5 | $ 810
Sensor de temperatura DHT22 | $ 83 | 5 | $ 415
Sensor de humo MQ-2 | $ 63 | 5 | $ 315
Sensor de flama KY-026 | $ 25 | 5 | $ 125
Sensor ultrasónico HC-SR04 | $ 54 | 1 | $ 54
Sensor infrarrojo FC-51 | $ 41 | 2 | $ 82
Modulo GPS Neo-6 | $ 40 | 5 | $ 700
Driver L298D | $ 99 | 1 | $ 99
Baterías 18650 3.7V | $ 125 | 2 | $ 250
Switch Dos posiciones | $ 40 | 1 | $ 40
Porta pilas | $ 15 | 2 | $ 30
Motorreductores | $ 40 | 4 | $ 160
Llantas | $ 15 | 4 | $ 60
Chasis | $ 200 | 1 | $ 200
Bomba de agua 5V | $ 63 | 1 | $ 63
Manguera | $ 15 | 2 | $ 30
Carcasa para módulos | $ 60 | 5 | $ 300
Carrocería Robot | $ 200 | 1 | $ 200
Servomotor SG90 | $ 60 | 1 | $ 60
Impresiones 3D | $ 30 | 5 | $ 150
PCBs | $ 100 | 5 | $ 500
Material de soldadura | $ 200 | 1 | $ 200
Cable | $ 8 | 3 | $ 24
Total | | | $ 4,867

Por otro lado, las herramientas que serán clave para el desarrollo del proyecto son las siguientes:

- Impresora 3D para prototipos
- Soldador y estaño para conexiones eléctricas
- Multímetro y osciloscopio para pruebas electrónicas

Y, por último, para ser capaces de desarrollar este proyecto, se requiere el uso de cierta infraestructura, en este caso se habla de los softwares a utilizar, algunos de ellos son los siguientes:

Arduino IDE y PlatformIO para la programación del ESP32

Servicio Cloud (Firebase, Azure, AWS)

Software de diseño CAD (SolidWorks, Fusion 360) para modelado del carrito.

Software de simulación (Proteus, Tinkercad) para pruebas previas.

Power BI o Excel para análisis de datos de sensores.

# Conclusión

Morales Escobedo Erick Rubén

Se espera que el sistema desarrollado sea funcional y capaz de detectar y mitigar incendios en entornos simulados. Si bien aún faltan detalles por definir, a largo plazo, este proyecto podría adaptarse a aplicaciones industriales o a entornos de emergencia reales, aumentando su impacto y utilidad en la prevención y control de incendios. En resumen, la complejidad de establecer un robot autónomo, preciso y confiable, que utiliza información proveniente de la nube puede conllevar múltiples desafíos que requieren una planificación muy detallada y un proceso iterativo de pruebas para lograr un sistema robusto y funcional.

Sánchez Meléndez Oswaldo

Considero que este proyecto aborda una problemática real y de gran importancia mediante la implementación de tecnologías avanzadas y conocimientos técnicos sólidos. Al finalizar el desarrollo, espero contar con un prototipo funcional en el que los módulos de monitoreo detecten incendios con alta precisión, la comunicación IoT opere de manera eficiente y el vehículo autónomo responda de forma efectiva. Este sistema automatizado de detección y respuesta contra incendios no solo demostrará su viabilidad técnica, sino que también tendrá un gran potencial de escalabilidad y aplicación en entornos reales.

Constante Maldonado Kevin Yair

En lo personal, considero que esta propuesta contiene un gran potencial que puede ser explotado y obtener un gran beneficio de esta. Hoy en día no se ha tenido gran avance en este rubro de la automoción y los robots capaces de ejecutar tareas de emergencia como lo puede ser apagar un incendio. Creo que nuestra propuesta de un sistema basado en GPS es bastante útil y que puede ser utilizada en cualquier tipo de contexto, ya sea domestico o industrial Gracias a esto, se convierte en una propuesta muy viable y que traerá consigo muchos beneficios.

# Referencias

- Azeta, J., Ayoade, I., Nwakanma, C., & Akande, T. (2023). Implementing a Prototype Autonomous Fire Detecting and Firefighting Robot. MDPI. https://doi.org/10.20944/preprints202305.2010.v1
- Cortes, Á. J. B., Cruz, E. M., Barrientos, A. G., Jiménez, N. P., Almaraz, M. X. H., Flores, A. M., & Marroquín, A. (2023). Mobile robotic platform IoT-based for LP gas detection. LACCEI. https://doi.org/10.18687/laccei2023.1.1.1470
- Laínez Apolinario, W. P., & Navarrete Buste, G. E. (2024). Implementación de un prototipo de monitoreo para la visualización en tiempo real de vehículos utilizando GPS y ESP32 (Tesis de pregrado, Universidad Politécnica Salesiana). Repositorio Digital UPS. https://dspace.ups.edu.ec/bitstream/123456789/29212/4/UPS-GT005841.pdf
- López-Prieto, J. F., Quijano, C. E., Moncayo, R. A., Piedrahita, J. H., Jiménez, J. D., Navarro, N. D., & Angarita, I. I. (2015). Diseño y prototipado de un robot explorador que soporte las actividades de los bomberos. Memorias.
- Palaniappan, A., Muthiah, R., & Sundaram, M. T. (2023). ZigBee enabled IoT based intelligent lane control system for autonomous agricultural electric vehicle application. SoftwareX, 23, 101512.
- Raafeek, A. R. M., Satheeskanth, N., Joy Mathavan, J., & Kunaraj, A. (2022). IoT based guided fire fighting vehicle. IOP Conference Series: Materials Science and Engineering, 1258, 012062. https://doi.org/10.1088/1757-899X/1258/1/012062
- Rehman, A., Qureshi, M. A., Ali, T., Irfan, M., Abdullah, S., Yasin, S., ... & Węgrzyn, M. (2021). Smart fire detection and deterrent system for human savior by using internet of things (IoT). Energies, 14(17), 5500.
- Talavera, N. F., Roldán‐Gómez, J. J., Martín, F., & Rodriguez‐Sanchez, M. C. (2023). An autonomous ground robot to support firefighters’ interventions in indoor emergencies. Journal Of Field Robotics, 40(3), 614-625. https://doi.org/10.1002/rob.22150
- Vyshnavi, M. B., Satheesh, A., Suresh, S. S., & Manikandan, L. C. (2020). IoT Technology Based Fire-Fighter Robot. International Journal of Scientific Research in Computer Science, Engineering and Information Technology, 6(3), 934-941. https://doi.org/10.32628/CSEIT2063187
- Xavier, K. L. B. L., & Nanayakkara, V. K. (2022). Development of an early fire detection technique using a passive infrared sensor and deep neural networks. Fire oTechnology, 58(6), 3529-3552.

# Anexos

## Repartición de tareas del equipo

Oswaldo Sánchez Meléndez: Redacción del resumen, introducción y planteamiento del problema. Redacción del objetivo general y los objetivos de control. Desarrollo de lo relacionado al control en la metodología y el cronograma.

Erick Rubén Morales Escobedo: Alcances y limitaciones del proyecto, justificación técnica, desarrollo de objetivos y metodología del diseño electrónico.

Kevin Yair Constante Maldonado: Apoyo en la definición general del proyecto, parte de la metodología y cronograma, así como la creación del plan inicial de recursos.

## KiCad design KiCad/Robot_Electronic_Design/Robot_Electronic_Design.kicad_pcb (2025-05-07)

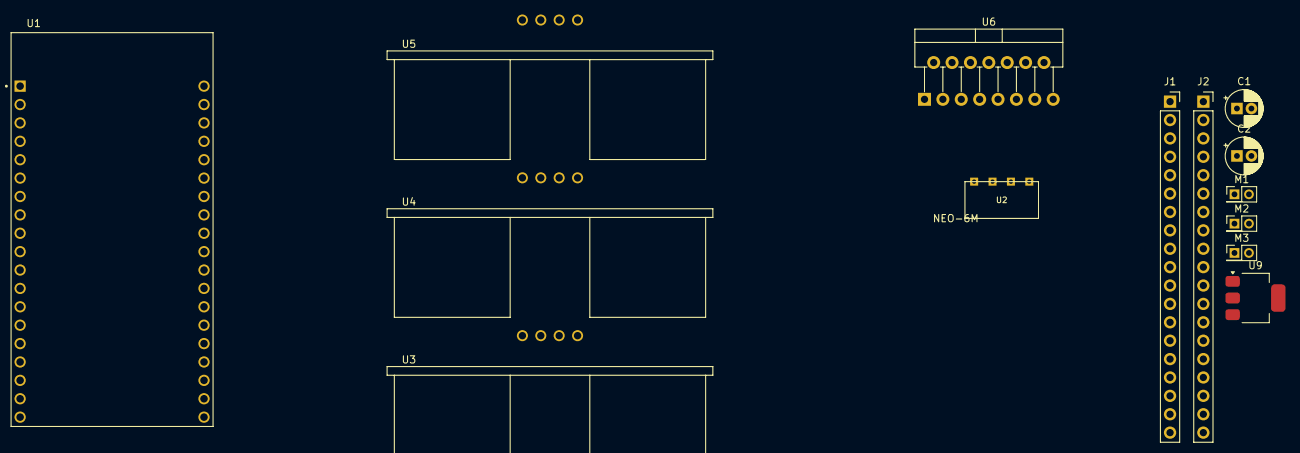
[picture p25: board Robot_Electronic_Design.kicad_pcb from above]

Board: 2 copper layers, 14 parts (0 on the bottom side), 7 nets, no tracks yet.

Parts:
C1, C2: 10uF; CP_Radial_D5.0mm_P2.00mm
J1, J2: Conn_01x19_Female; PinSocket_1x19_P2.54mm_Vertical
M1, M2: Motor_DC; PinHeader_2x01_P2.00mm_Vertical
M3: Water Pump; PinHeader_2x01_P2.00mm_Vertical
U1: ESP32-DEVKITC-32D; MODULE_ESP32-DEVKITC-32D
U2: NEO-6M
U3, U4, U5: HC-SR04; XCVR_HC-SR04
U6: L298N; TO-220-15_P2.54x2.54mm_StaggerOdd_Lead4.58mm_Vertical
U9: AMS1117-5.0; SOT-223-3_TabPin2

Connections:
/MOTOR_1_OUT1: M1.1 (+), U6.2 (OUT1)
/MOTOR_1_OUT2: M1.2 (-), U6.3 (OUT2)
/MOTOR_2_OUT1: M2.1 (+), U6.13 (OUT3)
/MOTOR_2_OUT2: M2.2 (-), U6.14 (OUT4)
GND: C1.2, C2.2, U3.4 (GND), U4.4 (GND), U5.4 (GND), U6.8 (GND), U9.1 (GND)
VCC: C1.1, U6.4 (Vs), U9.3 (VI)
Vin: C2.1, U3.1 (VCC), U4.1 (VCC), U5.1 (VCC), U6.9 (Vss), U9.2 (VO)

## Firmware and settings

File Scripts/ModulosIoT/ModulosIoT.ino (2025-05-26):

// For reference, please visit https://github.com/azure/azure-sdk-for-c. 

 

// C99 libraries 

#include <cstdlib> 

#include <string.h> 

#include <time.h> 

 

// Libraries for MQTT client and WiFi connection 

#include <WiFi.h> 

#include <mqtt_client.h> 

 

// Azure IoT SDK for C includes 

#include <az_core.h> 

#include <az_iot.h> 

#include <azure_ca.h> 

 

// Additional sample headers 

#include "AzIoTSasToken.h" 

#include "SerialLogger.h" 

#include "iot_configs.h" 

 

// Librerías de usuario 

#include <TinyGPS++.h> 

#include <HardwareSerial.h> 

#include <DHT.h> 

 

#define Flame1Pin 33     // Sensor de flama (DO) 

#define Flame2Pin 27     // Sensor de flama (DO) 

#define Flame3Pin 21     // Sensor de flama (DO) 

#define Flame4Pin 19     // Sensor de flama (DO) 

#define AlarmPin 18     // Buzzer 

#define LEDPin 14     // LED indicador 

#define DHTPIN 4    // Pin del sensor DHT22 

#define DHTTYPE DHT22 

 

const float TEMP_UMBRAL = 50.0; // Temperatura mínima para considerar fuego 

 

// Objetos de sensores 

TinyGPSPlus gps; 

HardwareSerial gpsSerial(2); 

DHT dht(DHTPIN, DHTTYPE); 

 

int satelites = 0; 

int hdop = 0; 

double latitud = 0.0; 

double longitud = 0.0; 

int latEntero = 0; 

int latDecimal = 0; 

int lonEntero = 0; 

int lonDecimal = 0; 

bool fuegoDetectado = false; 

bool dataIsValid = false; 

bool isBlocked = false; 

int tiempoInicial = 0; 

int tiempoAlertaSimulada = 25000; 

 

// When developing for your own Arduino-based platform, 

// please follow the format '(ard;<platform>)'. 

#define AZURE_SDK_CLIENT_USER_AGENT "c%2F" AZ_SDK_VERSION_STRING "(ard;esp32)" 

 

// Utility macros and defines 

#define sizeofarray(a) (sizeof(a) / sizeof(a[0])) 

#define NTP_SERVERS "pool.ntp.org", "time.google.com", "time.windows.com" 

#define MQTT_QOS1 1 

#define DO_NOT_RETAIN_MSG 0 

#define SAS_TOKEN_DURATION_IN_MINUTES 60 

#define UNIX_TIME_NOV_13_2017 1510592825 

 

#define PST_TIME_ZONE -8 

#define PST_TIME_ZONE_DAYLIGHT_SAVINGS_DIFF 1 

 

#define GMT_OFFSET_SECS (PST_TIME_ZONE * 3600) 

#define GMT_OFFSET_SECS_DST ((PST_TIME_ZONE + PST_TIME_ZONE_DAYLIGHT_SAVINGS_DIFF) * 3600) 

 

// Translate iot_configs.h defines into variables used by the sample 

static const char* ssid = IOT_CONFIG_WIFI_SSID; 

static const char* password = IOT_CONFIG_WIFI_PASSWORD; 

static const char* host = IOT_CONFIG_IOTHUB_FQDN; 

static const char* mqtt_broker_uri = "mqtts://" IOT_CONFIG_IOTHUB_FQDN; 

static const char* device_id = IOT_CONFIG_DEVICE_ID; 

static const int mqtt_port = AZ_IOT_DEFAULT_MQTT_CONNECT_PORT; 

 

// Memory allocated for the sample's variables and structures. 

static esp_mqtt_client_handle_t mqtt_client; 

static az_iot_hub_client client; 

 

static char mqtt_client_id[128]; 

static char mqtt_username[256]; 

static char mqtt_password[200]; 

static uint8_t sas_signature_buffer[256]; 

static unsigned long next_telemetry_send_time_ms = 0; 

static char telemetry_topic[128] = "devices/DetectionModule/messages/events/"; 

static uint32_t telemetry_send_count = 0; 

static String telemetry_payload = "{}"; 

 

#define INCOMING_DATA_BUFFER_SIZE 128 

static char incoming_data[INCOMING_DATA_BUFFER_SIZE]; 

 

// Auxiliary functions 

#ifndef IOT_CONFIG_USE_X509_CERT 

static AzIoTSasToken sasToken( 

    &client, 

    AZ_SPAN_FROM_STR(IOT_CONFIG_DEVICE_KEY), 

    AZ_SPAN_FROM_BUFFER(sas_signature_buffer), 

    AZ_SPAN_FROM_BUFFER(mqtt_password)); 

#endif // IOT_CONFIG_USE_X509_CERT 

 

static void connectToWiFi() 

{ 

  Logger.Info("Connecting to WIFI SSID " + String(ssid)); 

 

  WiFi.mode(WIFI_STA); 

  WiFi.disconnect(); 

  delay(100); 

  WiFi.begin(ssid, password); 

  while (WiFi.status() != WL_CONNECTED) 

  { 

    delay(500); 

    Serial.print("."); 

  } 

 

  Serial.println(""); 

 

  Logger.Info("WiFi connected, IP address: " + WiFi.localIP().toString()); 

} 

 

static void initializeTime() 

{ 

  Logger.Info("Setting time using SNTP"); 

 

  configTime(GMT_OFFSET_SECS, GMT_OFFSET_SECS_DST, NTP_SERVERS); 

  time_t now = time(NULL); 

  while (now < UNIX_TIME_NOV_13_2017) 

  { 

    delay(500); 

    Serial.print("."); 

    now = time(nullptr); 

  } 

  Serial.println(""); 

  Logger.Info("Time initialized!"); 

} 

 

void receivedCallback(char* topic, byte* payload, unsigned int length) 

{ 

  Logger.Info("Received ["); 

  Logger.Info(topic); 

  Logger.Info("]: "); 

  for (int i = 0; i < length; i++) 

  { 

    Serial.print((char)payload[i]); 

  } 

  Serial.println(""); 

} 

 

#if defined(ESP_ARDUINO_VERSION_MAJOR) && ESP_ARDUINO_VERSION_MAJOR >= 3 

static void mqtt_event_handler(void *handler_args, esp_event_base_t base, int32_t event_id, void *event_data) 

{ 

  (void)handler_args; 

  (void)base; 

  (void)event_id; 

 

  esp_mqtt_event_handle_t event = (esp_mqtt_event_handle_t)event_data; 

#else // ESP_ARDUINO_VERSION_MAJOR 

static esp_err_t mqtt_event_handler(esp_mqtt_event_handle_t event) 

{ 

#endif // ESP_ARDUINO_VERSION_MAJOR 

  switch (event->event_id) 

  { 

    int i, r; 

 

    case MQTT_EVENT_ERROR: 

      Logger.Info("MQTT event MQTT_EVENT_ERROR"); 

      break; 

    case MQTT_EVENT_CONNECTED: 

      Logger.Info("MQTT event MQTT_EVENT_CONNECTED"); 

 

      r = esp_mqtt_client_subscribe(mqtt_client, AZ_IOT_HUB_CLIENT_C2D_SUBSCRIBE_TOPIC, 1); 

      if (r == -1) 

      { 

        Logger.Error("Could not subscribe for cloud-to-device messages."); 

      } 

      else 

      { 

        Logger.Info("Subscribed for cloud-to-device messages; message id:" + String(r)); 

      } 

 

      break; 

    case MQTT_EVENT_DISCONNECTED: 

      Logger.Info("MQTT event MQTT_EVENT_DISCONNECTED"); 

      break; 

    case MQTT_EVENT_SUBSCRIBED: 

      Logger.Info("MQTT event MQTT_EVENT_SUBSCRIBED"); 

      break; 

    case MQTT_EVENT_UNSUBSCRIBED: 

      Logger.Info("MQTT event MQTT_EVENT_UNSUBSCRIBED"); 

      break; 

    case MQTT_EVENT_PUBLISHED: 

      Logger.Info("MQTT event MQTT_EVENT_PUBLISHED"); 

      break; 

    case MQTT_EVENT_DATA: 

      Logger.Info("MQTT event MQTT_EVENT_DATA"); 

 

      for (i = 0; i < (INCOMING_DATA_BUFFER_SIZE - 1) && i < event->topic_len; i++) 

      { 

        incoming_data[i] = event->topic[i]; 

      } 

      incoming_data[i] = '\0'; 

      Logger.Info("Topic: " + String(incoming_data)); 

 

      for (i = 0; i < (INCOMING_DATA_BUFFER_SIZE - 1) && i < event->data_len; i++) 

      { 

        incoming_data[i] = event->data[i]; 

      } 

      incoming_data[i] = '\0'; 

      Logger.Info("Data: " + String(incoming_data)); 

 

      break; 

    case MQTT_EVENT_BEFORE_CONNECT: 

      Logger.Info("MQTT event MQTT_EVENT_BEFORE_CONNECT"); 

      break; 

    default: 

      Logger.Error("MQTT event UNKNOWN"); 

      break; 

  } 

 

#if defined(ESP_ARDUINO_VERSION_MAJOR) && ESP_ARDUINO_VERSION_MAJOR >= 3 

#else // ESP_ARDUINO_VERSION_MAJOR 

  return ESP_OK; 

#endif // ESP_ARDUINO_VERSION_MAJOR 

} 

 

static void initializeIoTHubClient() 

{ 

  az_iot_hub_client_options options = az_iot_hub_client_options_default(); 

  options.user_agent = AZ_SPAN_FROM_STR(AZURE_SDK_CLIENT_USER_AGENT); 

 

  if (az_result_failed(az_iot_hub_client_init( 

          &client, 

          az_span_create((uint8_t*)host, strlen(host)), 

          az_span_create((uint8_t*)device_id, strlen(device_id)), 

          &options))) 

  { 

    Logger.Error("Failed initializing Azure IoT Hub client"); 

    return; 

  } 

 

  size_t client_id_length; 

  if (az_result_failed(az_iot_hub_client_get_client_id( 

          &client, mqtt_client_id, sizeof(mqtt_client_id) - 1, &client_id_length))) 

  { 

    Logger.Error("Failed getting client id"); 

    return; 

  } 

 

  if (az_result_failed(az_iot_hub_client_get_user_name( 

          &client, mqtt_username, sizeofarray(mqtt_username), NULL))) 

  { 

    Logger.Error("Failed to get MQTT clientId, return code"); 

    return; 

  } 

 

  Logger.Info("Client ID: " + String(mqtt_client_id)); 

  Logger.Info("Username: " + String(mqtt_username)); 

} 

 

static int initializeMqttClient() 

{ 

#ifndef IOT_CONFIG_USE_X509_CERT 

  if (sasToken.Generate(SAS_TOKEN_DURATION_IN_MINUTES) != 0) 

  { 

    Logger.Error("Failed generating SAS token"); 

    return 1; 

  } 

#endif 

 

  esp_mqtt_client_config_t mqtt_config; 

  memset(&mqtt_config, 0, sizeof(mqtt_config)); 

 

#if defined(ESP_ARDUINO_VERSION_MAJOR) && ESP_ARDUINO_VERSION_MAJOR >= 3 

    mqtt_config.broker.address.uri = mqtt_broker_uri; 

    mqtt_config.broker.address.port = mqtt_port; 

    mqtt_config.credentials.client_id = mqtt_client_id; 

    mqtt_config.credentials.username = mqtt_username; 

 

  #ifdef IOT_CONFIG_USE_X509_CERT 

    LogInfo("MQTT client using X509 Certificate authentication"); 

    mqtt_config.credentials.authentication.certificate = IOT_CONFIG_DEVICE_CERT; 

    mqtt_config.credentials.authentication.certificate_len = (size_t)sizeof(IOT_CONFIG_DEVICE_CERT); 

    mqtt_config.credentials.authentication.key = IOT_CONFIG_DEVICE_CERT_PRIVATE_KEY; 

    mqtt_config.credentials.authentication.key_len = (size_t)sizeof(IOT_CONFIG_DEVICE_CERT_PRIVATE_KEY); 

  #else // Using SAS key 

    mqtt_config.credentials.authentication.password = (const char*)az_span_ptr(sasToken.Get()); 

  #endif 

 

    mqtt_config.session.keepalive = 30; 

    mqtt_config.session.disable_clean_session = 0; 

    mqtt_config.network.disable_auto_reconnect = false; 

    mqtt_config.broker.verification.certificate = (const char*)ca_pem; 

    mqtt_config.broker.verification.certificate_len = (size_t)ca_pem_len; 

#else // ESP_ARDUINO_VERSION_MAJOR   

  mqtt_config.uri = mqtt_broker_uri; 

  mqtt_config.port = mqtt_port; 

  mqtt_config.client_id = mqtt_client_id; 

  mqtt_config.username = mqtt_username; 

 

#ifdef IOT_CONFIG_USE_X509_CERT 

  Logger.Info("MQTT client using X509 Certificate authentication"); 

  mqtt_config.client_cert_pem = IOT_CONFIG_DEVICE_CERT; 

  mqtt_config.client_key_pem = IOT_CONFIG_DEVICE_CERT_PRIVATE_KEY; 

#else // Using SAS key 

  mqtt_config.password = (const char*)az_span_ptr(sasToken.Get()); 

#endif 

 

  mqtt_config.keepalive = 30; 

  mqtt_config.disable_clean_session = 0; 

  mqtt_config.disable_auto_reconnect = false; 

  mqtt_config.event_handle = mqtt_event_handler; 

  mqtt_config.user_context = NULL; 

  mqtt_config.cert_pem = (const char*)ca_pem; 

#endif // ESP_ARDUINO_VERSION_MAJOR 

 

  mqtt_client = esp_mqtt_client_init(&mqtt_config); 

 

  if (mqtt_client == NULL) 

  { 

    Logger.Error("Failed creating mqtt client"); 

    return 1; 

  } 

 

#if defined(ESP_ARDUINO_VERSION_MAJOR) && ESP_ARDUINO_VERSION_MAJOR >= 3 

    esp_mqtt_client_register_event(mqtt_client, MQTT_EVENT_ANY, mqtt_event_handler, NULL); 

#endif // ESP_ARDUINO_VERSION_MAJOR 

 

  esp_err_t start_result = esp_mqtt_client_start(mqtt_client); 

 

  if (start_result != ESP_OK) 

  { 

    Logger.Error("Could not start mqtt client; error code:" + start_result); 

    return 1; 

  } 

  else 

  { 

    Logger.Info("MQTT client started"); 

    return 0; 

  } 

} 

 

/* 

 * @brief           Gets the number of seconds since UNIX epoch until now. 

 * @return uint32_t Number of seconds. 

 */ 

static uint32_t getEpochTimeInSecs() { return (uint32_t)time(NULL); } 

 

static void establishConnection() 

{ 

  connectToWiFi(); 

  initializeTime(); 

  initializeIoTHubClient(); 

  (void)initializeMqttClient(); 

} 

 

static void generateTelemetryPayload(String message) 

{ 

  // You can generate the JSON using any lib you want. Here we're showing how to do it manually, for simplicity. 

  // This sample shows how to generate the payload using a syntax closer to regular delevelopment for Arduino, with 

  // String type instead of az_span as it might be done in other samples. Using az_span has the advantage of reusing the  

  // same char buffer instead of dynamically allocating memory each time, as it is done by using the String type below. 

  telemetry_payload = message; 

} 

 

static void sendTelemetry(String message) 

{ 

  Logger.Info("Sending telemetry ..."); 

 

  // The topic could be obtained just once during setup, 

  // however if properties are used the topic need to be generated again to reflect the 

  // current values of the properties. 

  if (az_result_failed(az_iot_hub_client_telemetry_get_publish_topic( 

          &client, NULL, telemetry_topic, sizeof(telemetry_topic), NULL))) 

  { 

    Logger.Error("Failed az_iot_hub_client_telemetry_get_publish_topic"); 

    return; 

  } 

 

  generateTelemetryPayload(message); 

 

  if (esp_mqtt_client_publish( 

          mqtt_client, 

          telemetry_topic, 

          (const char*)telemetry_payload.c_str(), 

          telemetry_payload.length(), 

          MQTT_QOS1, 

          DO_NOT_RETAIN_MSG) 

      == 0) 

  { 

    Logger.Error("Failed publishing"); 

  } 

  else 

  { 

    Logger.Info("Message published successfully"); 

  } 

} 

 

// Arduino setup and loop main functions. 

void setup() 

{ 

  establishConnection(); 

   

  // Pines de entrada 

  pinMode(Flame1Pin, INPUT); 

  pinMode(Flame2Pin, INPUT); 

  pinMode(Flame3Pin, INPUT); 

  pinMode(Flame4Pin, INPUT); 

 

  //Pines de salida 

  pinMode(AlarmPin, OUTPUT); 

  pinMode(LEDPin, OUTPUT); 

 

  // Inicializar sensores 

  dht.begin(); 

  gpsSerial.begin(9600, SERIAL_8N1, 16, 17); // RX=16, TX=17 

 

  // Esperar a que los sensores den lecturas válidas 

  while (!dataIsValid) 

  { 

    // Lectura del GPS 

    while (gpsSerial.available() > 0) 

    { 

      gps.encode(gpsSerial.read()); 

    } 

 

    // Extraer valores del gps 

    satelites = gps.satellites.value(); 

    hdop = gps.hdop.value(); 

    latitud = redondearDecimales(gps.location.lat(), 7); 

    longitud = redondearDecimales(gps.location.lng(), 7); 

 

    // Imprimir lecturas de GPS 

    Serial.println("Satelites = " + String(satelites) + "\nHDOP = " + String(hdop) + "\nCoordenadas = " + String(latitud) +  ", " + String(longitud)); 

 

    // Verificar que las lecturas sean válidas 

    if (satelites >= 4 && hdop <= 300) 

    { 

        // Imprimir que las lecturas son válidas y actualizar flag 

        Serial.println("Data is Valid"); 

        tiempoInicial = millis(); 

        dataIsValid = true; 

    } 

  }   

} 

 

void loop() 

{ 

  if (WiFi.status() != WL_CONNECTED) 

  { 

    connectToWiFi(); 

  } 

 

  if (sasToken.IsExpired()) 

  { 

    Logger.Info("SAS token expired; reconnecting with a new one."); 

    (void)esp_mqtt_client_destroy(mqtt_client); 

    initializeMqttClient(); 

  } 

   

  if (!isBlocked) 

  { 

    //float temp = dht.readTemperature(); 

    int flame1 = digitalRead(Flame1Pin); 

    int flame2 = digitalRead(Flame2Pin); 

    int flame3 = digitalRead(Flame3Pin); 

    int flame4 = digitalRead(Flame4Pin); 

 

    if (isnan(temp)) 

    { 

      Serial.println("Error al leer temperatura"); 

    } 

    else 

    { 

      Serial.print("Temperatura: "); 

      Serial.print(temp); 

      Serial.println(" °C"); 

    } 

 

    if (flame1 == HIGH || flame2 == HIGH || flame3 == HIGH || flame4 == HIGH) 

    { 

      fuegoDetectado = true; 

    } 

 

    if (fuegoDetectado && temp > TEMP_UMBRAL) 

    { 

      EnviarAlerta();  

    } 

  } 

} 

 

void EnviarAlerta() 

{ 

  digitalWrite(AlarmPin, HIGH); 

  digitalWrite(LEDPin, HIGH); 

  Serial.println("Temperatura alta y flama presente"); 

 

  // Lectura del GPS 

  while (gpsSerial.available() > 0) 

  { 

    gps.encode(gpsSerial.read()); 

  } 

 

  // Extraer valores del gps 

  satelites = gps.satellites.value(); 

  hdop = gps.hdop.value(); 

  latitud = redondearDecimales(gps.location.lat(), 7); 

  longitud = redondearDecimales(gps.location.lng(), 7); 

 

  // Imprimir lecturas de GPS 

  Serial.println("Enviando coordenadas: " + String(latitud) +  ", " + String(longitud)); 

  Serial.println("Con calidad: Satelites = " + String(satelites) + ", HDOP = " + String(hdop)); 

   

  int latEntero = (int)latitud; 

  int latDecimal = abs((int)((latitud - latEntero) * 10000000)); 

  int lonEntero = (int)longitud; 

  int lonDecimal = abs((int)((longitud - lonEntero) * 10000000)); 

 

  String resultado = String(latEntero) + "," + String(latDecimal) + "," + String(lonEntero) + "," + String(lonDecimal); 

 

  sendTelemetry(resultado); 

  isBlocked = true; 

} 

 

// Función para redondear doubles a 2 decimales 

double redondearDecimales(double numero, double decimales) 

{ 

    double factor = pow(10, decimales); 

    return roundf(numero * factor) / factor; 

}

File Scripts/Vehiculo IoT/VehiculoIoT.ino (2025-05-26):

/* --- Librerías --- */  

#include <WiFi.h> 

#include <WiFiClientSecure.h> 

#include <PubSubClient.h> 

#include <Wire.h> 

#include <QMC5883LCompass.h> 

#include <TinyGPS++.h> 

#include <math.h> 

#include "time.h" 

 

/* --- Defines --- */  

// Pines para el sensor ultrasónico 

#define USTrigPin 26 

#define USEchoPin 27 

// Pines para el GPS 

#define RXPin 16 

#define TXPin 17 

// Pines para el L298N 

#define EN1Pin 4 

#define EN2Pin 32 

#define IN1Pin 18 

#define IN2Pin 19 

#define IN3Pin 33 

#define IN4Pin 25 

// Pin para la bomba 

#define BombaPin 23 

// Velocidad de transmisión de datos con el GPS y declinación en Monterrey 

#define GPS_Baud 9600 

#define declinacion 4.44 

// Tamaño del buffer para la recepción de mensajes 

#define INCOMING_DATA_BUFFER_SIZE 32 

 

/* --- Datos de conectividad --- */  

// Credenciales de red 

const char* ssid = ""; 

const char* password =  ""; 

// Credenciales Azure 

const char* iotHubName = ""; 

const char* deviceId = ""; 

const char* sasToken = ""; 

const char* mqttServer = iotHubName; 

const int mqttPort = 8883; 

String mqttUsername = ""; 

// Certificado raíz usado por Azure 

const char* azure_root_ca = \ 

"-----BEGIN CERTIFICATE-----\n" \ 

"MIIDjjCCAnagAwIBAgIQAzrx5qcRqaC7KGSxHQn65TANBgkqhkiG9w0BAQsFADBh\n" \ 

"MQswCQYDVQQGEwJVUzEVMBMGA1UEChMMRGlnaUNlcnQgSW5jMRkwFwYDVQQLExB3\n" \ 

"d3cuZGlnaWNlcnQuY29tMSAwHgYDVQQDExdEaWdpQ2VydCBHbG9iYWwgUm9vdCBH\n" \ 

"MjAeFw0xMzA4MDExMjAwMDBaFw0zODAxMTUxMjAwMDBaMGExCzAJBgNVBAYTAlVT\n" \ 

"MRUwEwYDVQQKEwxEaWdpQ2VydCBJbmMxGTAXBgNVBAsTEHd3dy5kaWdpY2VydC5j\n" \ 

"b20xIDAeBgNVBAMTF0RpZ2lDZXJ0IEdsb2JhbCBSb290IEcyMIIBIjANBgkqhkiG\n" \ 

"9w0BAQEFAAOCAQ8AMIIBCgKCAQEAuzfNNNx7a8myaJCtSnX/RrohCgiN9RlUyfuI\n" \ 

"2/Ou8jqJkTx65qsGGmvPrC3oXgkkRLpimn7Wo6h+4FR1IAWsULecYxpsMNzaHxmx\n" \ 

"1x7e/dfgy5SDN67sH0NO3Xss0r0upS/kqbitOtSZpLYl6ZtrAGCSYP9PIUkY92eQ\n" \ 

"q2EGnI/yuum06ZIya7XzV+hdG82MHauVBJVJ8zUtluNJbd134/tJS7SsVQepj5Wz\n" \ 

"tCO7TG1F8PapspUwtP1MVYwnSlcUfIKdzXOS0xZKBgyMUNGPHgm+F6HmIcr9g+UQ\n" \ 

"vIOlCsRnKPZzFBQ9RnbDhxSJITRNrw9FDKZJobq7nMWxM4MphQIDAQABo0IwQDAP\n" \ 

"BgNVHRMBAf8EBTADAQH/MA4GA1UdDwEB/wQEAwIBhjAdBgNVHQ4EFgQUTiJUIBiV\n" \ 

"5uNu5g/6+rkS7QYXjzkwDQYJKoZIhvcNAQELBQADggEBAGBnKJRvDkhj6zHd6mcY\n" \ 

"1Yl9PMWLSn/pvtsrF9+wX3N3KjITOYFnQoQj8kVnNeyIv/iPsGEMNKSuIEyExtv4\n" \ 

"NeF22d+mQrvHRAiGfzZ0JFrabA0UWTW98kndth/Jsw1HKj2ZL7tcu7XUIOGZX1NG\n" \ 

"Fdtom/DzMNU+MeKNhJ7jitralj41E6Vf8PlwUHBHQRFXGU7Aj64GxJUTFy8bJZ91\n" \ 

"8rGOmaFvE7FBcf6IKshPECBV1/MUReXgRPTqh5Uykw7+U0b6LJ3/iyK5S9kJRaTe\n" \ 

"pLiaWN0bfVKfjllDiIGknibVb63dDcY3fe0Dkhvld1927jyNxF1WW6LZZm6zNTfl\n" \ 

"MrY=\n" \ 

"-----END CERTIFICATE-----\n"; 

// Variables para establecer hora local 

#define NTP_SERVERS "pool.ntp.org", "time.google.com", "time.windows.com" 

const long gmtOffset_sec = -21600; 

const int daylightOffset_sec = 0; 

 

/* --- Constantes --- */ 

// Velocidades (0-255) 

const int VELOCIDAD_AVANCE = 240; 

const int VELOCIDAD_GIRO = 180; 

// Tolerancias 

const double TOLERANCIA_GRADOS = 17.0; 

const double TOLERANCIA_METROS = 3; 

const double TOLERANCIA_OBSTACULO = 20; // cm 

// Constante de control proporcional de giro 

const double KP_CONTROL = 0.033; 

// Tiempos (segundos) 

const double TIEMPO_EVASION = 1; 

const double TIEMPO_MINIMO_GIRO = 0.2; 

// Constantes para cálculos de distancias 

const double RADIO_TIERRA = 6371000.0; // en metros 

const double GRADOS_LATITUD_METROS = 111320.0; // Aproximado 

// Velocidad del sonido para calcular distancias con el sensor ultrasónico 

const double soundSpeed = 0.034; 

 

/* --- Variables --- */ 

// Variables de clases 

TinyGPSPlus gps; 

QMC5883LCompass compass; 

HardwareSerial gpsSerial(2); 

WiFiClientSecure secureClient; 

PubSubClient mqttClient(secureClient); 

// Variables relacionadas a la orientación 

double bearing = 0.0; 

double heading = 0.0; 

int minX = 32767, maxX = -32768; 

int minY = 32767, maxY = -32768; 

// Variables relacionadas a la localización 

int satelites = 0; 

int hdop = 0; 

double latitud = 0.0; 

double longitud = 0.0; 

double latitudObj = 0.0; 

double longitudObj = 0.0; 

double latitudIni = 0.0; 

double longitudIni = 0.0; 

// Variables auxiliares para la reconstrucción de mensajes 

int latitudObjEntero = 0; 

int latitudObjDecimal = 0; 

int longitudObjEntero = 0; 

int longitudObjDecimal = 0; 

// Variables para controlar los tiempos de giro (en base a la Kp) 

double tiempoDeGiro = 0.0; 

unsigned long tiempoGiroStart = 0; 

// Variable para almacenar distancia al objetivo (módulo o HOME) 

double distanciaAlObj = 0.0; 

// Variables para el sensor ultrasónico 

double distance = 0;  

long duration; 

// Flags 

bool mensaje = false; 

bool conectado = false; 

bool dataIsValid = false; 

bool enGiro = false; 

 

// SETUP 

void setup() 

{ 

  // Inicializar comunicación Serial y conectar con el IoT Hub 

  Serial.begin(115200); 

  Connect(); 

 

  //Configuración del GPS 

  gpsSerial.begin(GPS_Baud, SERIAL_8N1, RXPin, TXPin); 

 

  // Configuración de la brújula 

  Wire.begin(); 

  compass.init(); 

 

  // Configuración del motor L298N 

  pinMode(EN1Pin, OUTPUT); 

  pinMode(EN2Pin, OUTPUT); 

  pinMode(IN1Pin, OUTPUT); 

  pinMode(IN2Pin, OUTPUT); 

  pinMode(IN3Pin, OUTPUT); 

  pinMode(IN4Pin, OUTPUT); 

 

  // Configuración del sensor Ultrasonico 

  pinMode(USTrigPin, OUTPUT); 

  pinMode(USEchoPin, INPUT); 

 

  // Configuración de la Bomba 

  pinMode(BombaPin, OUTPUT); 

 

  // Confirmar que terminó el setup por Serial 

  Serial.println("Listo el Setup"); 

} 

 

// LOOP 

void loop()
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

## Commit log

2025-02-21 chore: Initial commit
    Create directory
    [Cronograma Proyecto IMTC.xlsx]
2025-03-02 Sync files with oneDrive
    [Cronograma Proyecto IMTC.xlsx]
2025-03-02 Add KiCad Projects
    [Fire_Detection_System.kicad_pcb, Fire_Detection_System.kicad_sch, Robot_Electronic_Design.kicad_pcb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]
2025-03-09 chore: Create Arduino Project
    - HTML add to library (html.h, html.cpp)
    [Robot_Electronic_Design.kicad_pcb]
2025-04-06 Update Kicad Files
    [Robot_Electronic_Design.kicad_pcb, Robot_Electronic_Design.kicad_sch]
2025-04-06 chore: Update Arduino Script
2025-04-06 fix: Arduino Script
2025-04-06 fix: Adding delay time for buttons
    [AvanceMC_GPS_Brujula.ino]
2025-04-06 chore: Update Arduino file
2025-05-07 test: DC Motors
    [Fire_Detection_System.kicad_pcb, Fire_Detection_System.kicad_sch, Robot_Electronic_Design.kicad_pcb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]
2025-05-07 fix: Motors DC ino file
    [Motores.ino]
2025-05-07 chore: Update DC Motors ino file
2025-05-07 chore: update DC Motors script
2025-05-08 Fix: Right Movement DC Motors script
    [Motores.ino]
2025-05-10 feat: Adding Compass Calibration
    [Fire_Detection_System.kicad_sch, Robot_Electronic_Design.kicad_sch]
